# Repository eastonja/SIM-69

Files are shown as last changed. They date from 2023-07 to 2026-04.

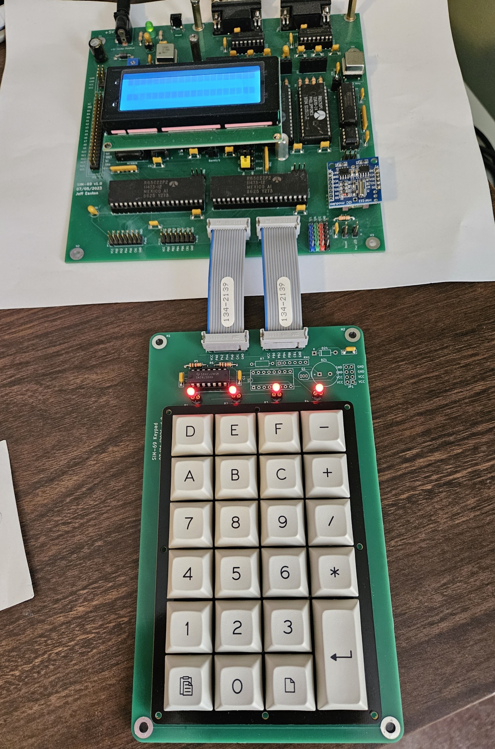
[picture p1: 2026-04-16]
SIM-69 Keypad v1.0/SIM-69-KeypadOperation.JPG

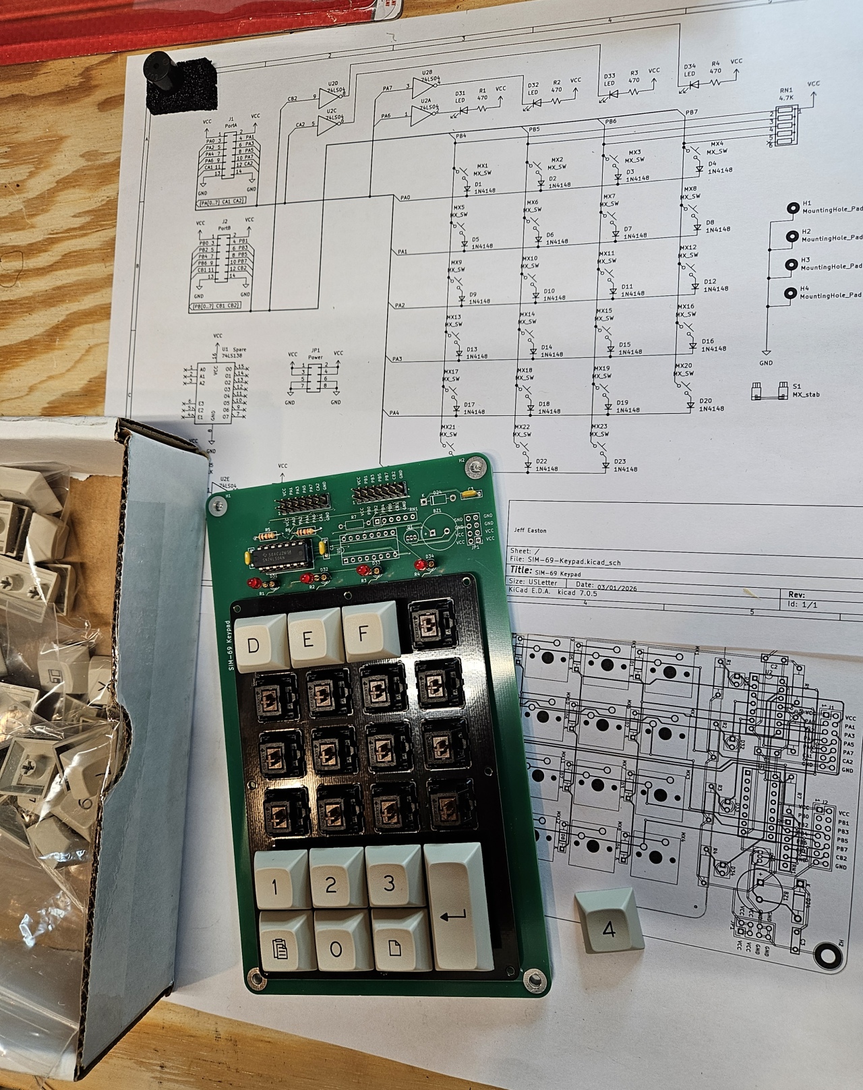
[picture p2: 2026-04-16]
SIM-69 Keypad v1.0/SIM-69-KeypadAssembly.JPG

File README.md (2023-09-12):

6809 based Retro Computing project.  Mini-ITX sized board with 6809 at 2Mhz, 32K/64K RAM, ROM, 8K-32K EEPROM,
20x4 LCD interface, 2 RS-232 Serial ports (6551), 4 8-bit parallel ports (6522), I2C interface(PCF 8584), 
RTC (via typical I2C module), 24LC256 serial EEPROM.
Can be used as a SBC for experimenting, or mounted in a mini-ITX case with Peter Hizalev's VT100 terminal
daughter board for a self contained computer.

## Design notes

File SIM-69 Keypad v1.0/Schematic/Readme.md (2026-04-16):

KiCad 7.x schematic and Bill of Materials for Keypad

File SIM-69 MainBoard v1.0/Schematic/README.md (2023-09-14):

KiCad 7.x schematic and Bill of Materials

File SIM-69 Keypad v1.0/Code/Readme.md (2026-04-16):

Demo Assembly code for scanning keypad and setting LEDs

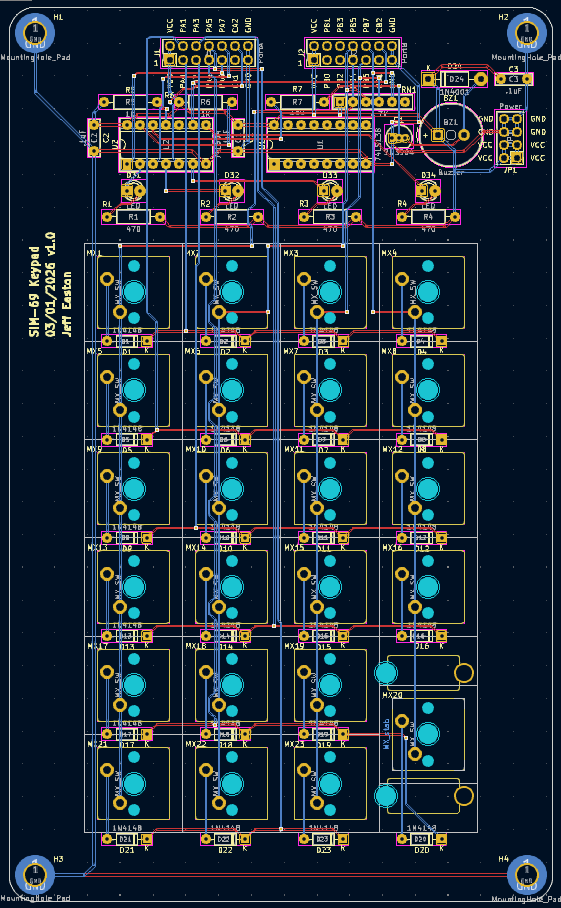
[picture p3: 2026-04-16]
SIM-69 Keypad v1.0/PCB/SIM-69-KeypadBRD.png

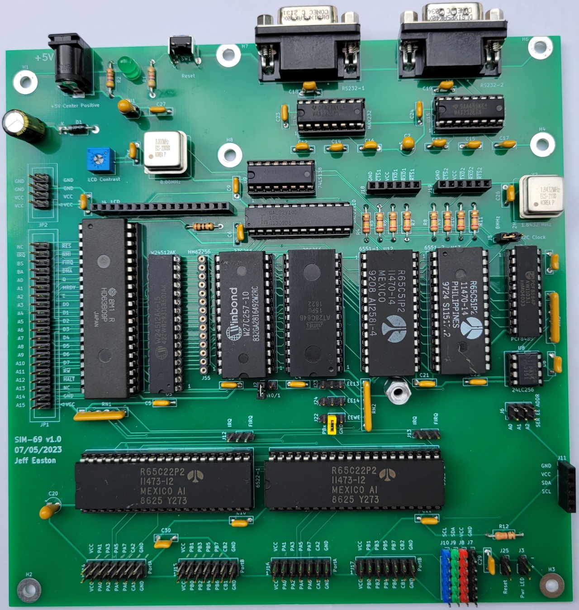
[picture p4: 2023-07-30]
SIM-69 MainBoard v1.0/SIM-69-PCB.jpg

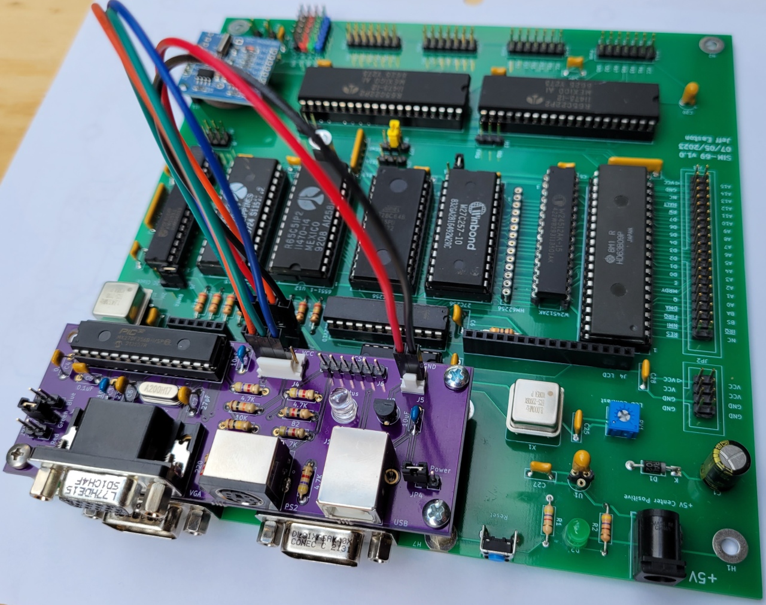
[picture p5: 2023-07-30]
SIM-69 MainBoard v1.0/SIM-69-TERM.jpg

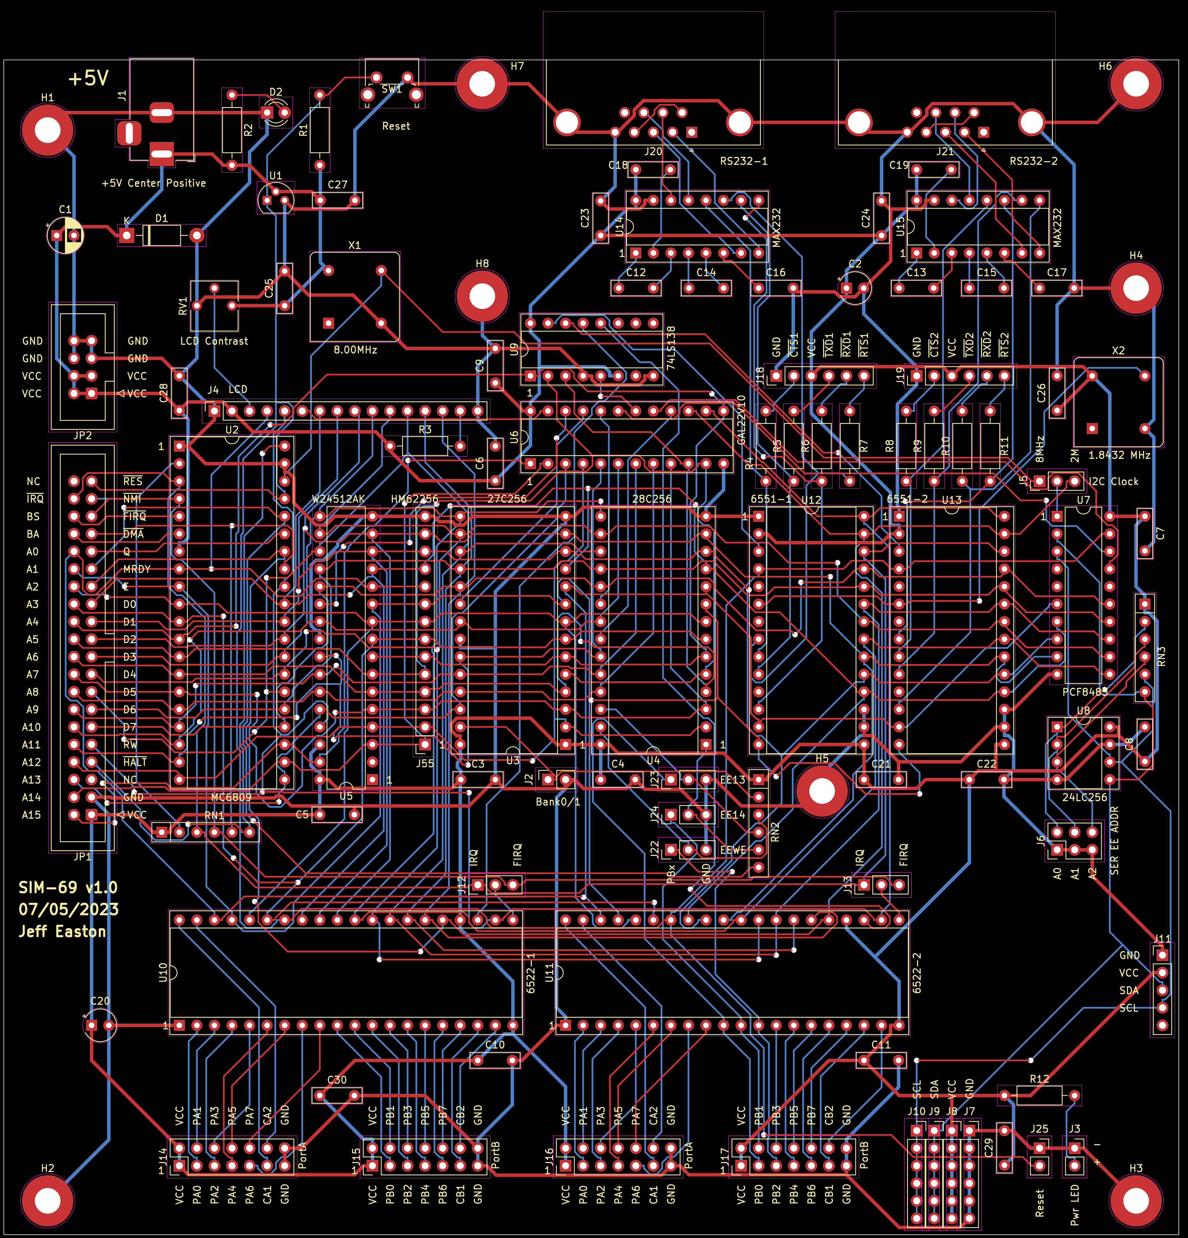
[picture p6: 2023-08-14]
SIM-69 MainBoard v1.0/PCB/SIM-69-brd.png

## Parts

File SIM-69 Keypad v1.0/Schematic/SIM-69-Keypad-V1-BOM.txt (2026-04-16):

				
Component Count:	74						
Ref	Qnty	Value	Cmp name	Footprint	Description	Vendor	DNP
BZ1	1	Buzzer	Buzzer	Buzzer_Beeper:Buzzer_TDK_PS1240P02BT_D12.2mm_H6.5mm	"Buzzer, polarized"		
"C1, C2, C3"	3	.1uF	C	Capacitor_THT:C_Rect_L7.0mm_W2.0mm_P5.00mm	Unpolarized capacitor		
D1 through D23	23	1N4148	D_Small	Diode_THT:D_DO-35_SOD27_P7.62mm_Horizontal	"Diode, small symbol"		
D24	1	1N4001	1N4002_1	Diode_THT:D_DO-41_SOD81_P10.16mm_Horizontal	"100V 1A General Purpose Rectifier Diode, DO-41"		
"D31, D32, D33, D34"	4	LED	LED	LED_THT:LED_D3.0mm	Light emitting diode		
"H1, H2, H3, H4"	4	MountingHole_Pad	MountingHole_Pad	MountingHole:MountingHole_3.7mm_Pad_TopBottom	Mounting Hole with connection		
J1	1	PortA	Conn_02x07_Odd_Even	Connector_PinHeader_2.54mm:PinHeader_2x07_P2.54mm_Vertical	"Generic connector, double row, 02x07, odd/even pin numbering scheme (row 1 odd numbers, row 2 even numbers)"		
J2	1	PortB	Conn_02x07_Odd_Even	Connector_PinHeader_2.54mm:PinHeader_2x07_P2.54mm_Vertical	"Generic connector, double row, 02x07, odd/even pin numbering scheme (row 1 odd numbers, row 2 even numbers)"		
JP1	1	Power	Conn_02x04_Odd_Even	Connector_PinHeader_2.54mm:PinHeader_2x04_P2.54mm_Vertical	"Generic connector, double row, 02x04, odd/even pin numbering scheme (row 1 odd numbers, row 2 even numbers)"		
MX1 through MX23	23	MX_SW	MX_SW_solder	PCM_marbastlib-mx:SW_MX_1u	"Push button switch, normally open, two pins, 45° tilted. Cherry MX Brown"		
Q1	1	2N3904	2N3904	Package_TO_SOT_THT:TO-92_Inline	"0.2A Ic, 40V Vce, Small Signal NPN Transistor, TO-92"		
"R1, R2, R3, R4"	4	470	R_Small_US	Resistor_THT:R_Axial_DIN0207_L6.3mm_D2.5mm_P10.16mm_Horizontal	"Resistor, small US symbol"		1/4W 5% carbon film
"R5, R6"	2	1K	R_Small_US	Resistor_THT:R_Axial_DIN0207_L6.3mm_D2.5mm_P10.16mm_Horizontal	"Resistor, small US symbol"		1/4W 5% carbon film
R7	1	180	R_Small_US	Resistor_THT:R_Axial_DIN0207_L6.3mm_D2.5mm_P10.16mm_Horizontal	"Resistor, small US symbol"		1/4W 5% carbon film
RN1	1	4.7K	R_Network05	"Resistor_THT:R_Array_SIP6 (Optional, depending on 6522 VIA mfr)"	"5 resistor network, star topology, bussed resistors, small symbol"		
S1	1	MX_stab	MX_stab	"PCM_marbastlib-mx:STAB_MX_P_2u, DUROCK Stabilizer V3 PCB Mount"	Cherry MX-style stabilizer	Amazon	
U1	1	74LS138	74LS138	Package_DIP:DIP-16_W7.62mm_Socket (Optional/ Spare)	Decoder 3 to 8 active low outputs		
U2	1	74LS04	74LS04	Package_DIP:DIP-14_W7.62mm_Socket	Hex Inverter		
							
			PCB	Sim-69 Keypad base PCB		JLCPCB	https://jlcpcb.com/
			Plate	"Nyquist Plate, Black FR4 (optional)"		Keebio	https://keeb.io/products/nyquist-case-plates
			2x7 ribbon cable/conn	"2x7 IDC dual row female connectors, 14 con. Ribbon cable"		Jameco/Amazon	
			KeyCaps	"DSA Flex Keycaps, Hexidecimal set and Numpad Modifier set in Biege"		Signature Plastics	https://spkeyboards.com/products/dsa-flex-sublimated-keycaps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

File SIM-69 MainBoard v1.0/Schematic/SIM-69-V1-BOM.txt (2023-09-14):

Reference	Value	Footprint	Datasheet	Sim.Device	Sim.Pins	Qty														
C1	470uF	Capacitor_THT:CP_Radial_D5.0mm_P2.50mm	~			1		EEU-FM1A471B Panasonic Electronic Components | Capacitors | DigiKey												
"C2, C20"	10uF	Capacitor_THT:CP_Radial_Tantal_D4.5mm_P2.50mm	~			2		TAP106K016SRW KYOCERA AVX | Capacitors | DigiKey												
"C3-C9, C11, C21-C27, C29, C30"	.1uF	Capacitor_THT:C_Rect_L7.0mm_W2.0mm_P5.00mm	~			17		SR211C104KARTR1 KYOCERA AVX | Capacitors | DigiKey												
"C10, C28"	.1uF	Capacitor_THT:C_Rect_L7.0mm_W2.0mm_P5.00mm	~			2		SR211C104KARTR1 KYOCERA AVX | Capacitors | DigiKey												
C12-C19	1uF	Capacitor_THT:C_Rect_L7.0mm_W2.0mm_P5.00mm	~			8		SR211C105KAR KYOCERA AVX | Capacitors | DigiKey												
D1	1N4002	Diode_THT:D_DO-41_SOD81_P10.16mm_Horizontal	http://www.vishay.com/docs/88503/1n4001.pdf	D	1=K 2=A	1		1N4002 Diode | Jameco Electronics												
D2	LED	LED_THT:LED_D3.0mm	~			1		SSL-LX5093GD-12V Lumex Opto/Components Inc. | Optoelectronics | DigiKey												
H1-H8	MountingHole_Pad	MountingHole:MountingHole_3.7mm_Pad_TopBottom	~			8														
J1	+5V Center Positive	Connector_BarrelJack:BarrelJack_Horizontal	~			1		"PJ-202AH CUI Devices | Connectors, Interconnects | DigiKey"												
J2	Bank0/1	Connector_PinSocket_2.54mm:PinSocket_1x02_P2.54mm_Vertical	~		1x2 pin header strip	1		"68000-220HLF Amphenol ICC (FCI) | Connectors, Interconnects | DigiKey"												
J3	Front Panel Power LED	Connector_PinSocket_2.54mm:PinSocket_1x02_P2.54mm_Vertical	~		1x2 pin header strip	1		"68000-220HLF Amphenol ICC (FCI) | Connectors, Interconnects | DigiKey"												
J4	LCD Interface	Connector_PinSocket_2.54mm:PinSocket_1x16_P2.54mm_Vertical	~		1x16 socket header strip	1		Vertical Header Receptacle TDH16SG-VP-R | Jameco Valuepro												
J5	I2C CLK	Connector_PinHeader_2.54mm:PinHeader_1x03_P2.54mm_Vertical	~		1x3 pin header strip	1		"68000-220HLF Amphenol ICC (FCI) | Connectors, Interconnects | DigiKey"												
J6	Ser ADDR	Connector_PinHeader_2.54mm:PinHeader_2x03_P2.54mm_Vertical	~		2x3 pin header strip	1		"67997-240HLF Amphenol ICC (FCI) | Connectors, Interconnects | DigiKey"												
J7	I2C GND	Connector_PinSocket_2.54mm:PinSocket_1x06_P2.54mm_Vertical	~		1x6 pin header strip	1		"colored .100"" pin strip Amazon"												
J8	I2C Vcc	Connector_PinSocket_2.54mm:PinSocket_1x06_P2.54mm_Vertical	~		1x6 pin header strip	1		"colored .100"" pin strip Amazon"												
J9	I2C SDA	Connector_PinSocket_2.54mm:PinSocket_1x06_P2.54mm_Vertical	~		1x6 pin header strip	1		"colored .100"" pin strip Amazon"												
J10	I2C SCL	Connector_PinSocket_2.54mm:PinSocket_1x06_P2.54mm_Vertical	~		1x6 pin header strip	1		"colored .100"" pin strip Amazon"												
J11	RTC Conn	Connector_PinHeader_2.54mm:PinHeader_1x05_P2.54mm_Vertical	~		1x5 socket header strip	1		"RS1-05-G Adam Tech | Connectors, Interconnects | DigiKey"												
"J12, J13"	6522 IRQ	Connector_PinHeader_2.54mm:PinHeader_1x03_P2.54mm_Vertical	~		1x3 pin header strip	2		"68000-220HLF Amphenol ICC (FCI) | Connectors, Interconnects | DigiKey"												
"J14, J16"	PortA	Connector_PinHeader_2.54mm:PinHeader_2x07_P2.54mm_Vertical	~		2x7 pin header strip	2		"67997-240HLF Amphenol ICC (FCI) | Connectors, Interconnects | DigiKey"												
"J15, J17"	PortB	Connector_PinHeader_2.54mm:PinHeader_2x07_P2.54mm_Vertical	~		2x7 pin header strip	2		"67997-240HLF Amphenol ICC (FCI) | Connectors, Interconnects | DigiKey"												
J18	Conn_Ser1	Connector_PinHeader_2.54mm:PinHeader_1x06_P2.54mm_Vertical	~		1x6 socket header strip	1		"RS1-06-G Adam Tech | Connectors, Interconnects | DigiKey"												
J19	Conn_Ser2	Connector_PinHeader_2.54mm:PinHeader_1x06_P2.54mm_Vertical	~		1x6 socket header strip	1		"RS1-06-G Adam Tech | Connectors, Interconnects | DigiKey"												
"J20, J21"	DE9_P	Connector_Dsub:DSUB-9_Male_Horizontal_P2.77x2.84mm_EdgePinOffset7.70mm_Housed_MountingHolesOffset9.12mm	 ~		DB9 Male rt angle	2		"DLS1XP5AK40X Conec | Connectors, Interconnects | DigiKey"												
J22	~{EEWE}	Connector_PinHeader_2.54mm:PinHeader_1x03_P2.54mm_Vertical	~		1x3 pin header strip	1		"68000-220HLF Amphenol ICC (FCI) | Connectors, Interconnects | DigiKey"												
J23	EE13	Connector_PinHeader_2.54mm:PinHeader_1x03_P2.54mm_Vertical	~		1x3 pin header strip	1		"68000-220HLF Amphenol ICC (FCI) | Connectors, Interconnects | DigiKey"												
J24	EE14	Connector_PinHeader_2.54mm:PinHeader_1x03_P2.54mm_Vertical	~		1x3 pin header strip	1		"68000-220HLF Amphenol ICC (FCI) | Connectors, Interconnects | DigiKey"												
J25	Front Panel Reset	Connector_PinSocket_2.54mm:PinSocket_1x02_P2.54mm_Vertical	~		1x2 pin header strip	1		"68000-220HLF Amphenol ICC (FCI) | Connectors, Interconnects | DigiKey"												
J55	HM62256	Connector_PinSocket_2.54mm:PinSocket_1x14_P2.54mm_Vertical	~		machined strip	1		SMC-1-30-1-GT Adam Technologies | Jameco												
JP1	EXP BUS	Connector_IDC:IDC-Header_2x20_P2.54mm_Vertical	~		2x20 pin header strip	1		"67997-240HLF Amphenol ICC (FCI) | Connectors, Interconnects | DigiKey"												
JP2	Power	Connector_IDC:IDC-Header_2x04_P2.54mm_Vertical	~		2x4 pin header strip	1		"67997-240HLF Amphenol ICC (FCI) | Connectors, Interconnects | DigiKey"												
R1	2.7K	Resistor_THT:R_Axial_DIN0207_L6.3mm_D2.5mm_P10.16mm_Horizontal	~			1		Carbon Film Resistor 1/4 Watt 2.7k Ohm | Jameco Valuepro												
"R2, R12"	470	Resistor_THT:R_Axial_DIN0207_L6.3mm_D2.5mm_P10.16mm_Horizontal	~			2		Carbon Film Resistor 1/4 Watt 470 Ohm | Jameco Valuepro												
R3	10	Resistor_THT:R_Axial_DIN0207_L6.3mm_D2.5mm_P10.16mm_Horizontal	~			1		Carbon Film Resistor 1/4 Watt 10 Ohm | Jameco Valuepro												
R4-R11	240	Resistor_THT:R_Axial_DIN0207_L6.3mm_D2.5mm_P10.16mm_Horizontal	~			8		Carbon Film Resistor 1/4 Watt 240 Ohm | Jameco Valuepro												
RN1-RN3	4.7K	Resistor_THT:R_Array_SIP6	http://www.vishay.com/docs/31509/csc.pdf			3		4606X-101-472LF Bourns Inc. | Resistors | DigiKey												
RV1	10K_Potentiometer	Potentiometer_THT:Potentiometer_Vishay_T73YP_Vertical	~			1		"T73YP103KT20 Vishay Sfernice | Potentiometers, Variable Resistors | DigiKey"												
SW1	SW_Push	Button_Switch_THT:SW_Tactile_SPST_Angled_PTS645Vx58-2LFS	~			1		PTS645VK58-2 LFS C&K | Switches | DigiKey							alternate: PTS645VM31-2 LFS C&K | Switches | DigiKey					alternate: PTS645VK312LFS C&K | Switches | DigiKey
U1	DS1813-5	Package_TO_SOT_THT:TO-92				1		DS1813-5+ Analog Devices Inc./Maxim Integrated | Integrated Circuits (ICs) | DigiKey								alternate: Microschip MCP130			alternate:10uf Tantlum cap	
U2	MC6809	Package_DIP:DIP-40_W15.24mm_Socket	http://pdf.datasheetcatalog.com/datasheet/motorola/MC68B09S.pdf			1		MC6809B or HD63B09P | Ebay												
U2		40Pin DIP socket						"DILB40P-223TLF Amphenol ICC (FCI) | Connectors, Interconnects | DigiKey"												
U3	27C256	Package_DIP:DIP-28_W15.24mm_Socket	http://ww1.microchip.com/downloads/en/DeviceDoc/doc0014.pdf			1		WinBond W27C257-10 | Ebay												
U3		28Pin DIP Socket						"DILB28P-223TLF Amphenol ICC (FCI) | Connectors, Interconnects | DigiKey"												
U4	28C256	Package_DIP:DIP-28_W15.24mm_Socket	http://ww1.microchip.com/downloads/en/DeviceDoc/doc0006.pdf			1		Atmel AT28C64B-15 (8Kx8) or AT28C256 (32Kx8) | Ebay												
U4		28Pin DIP Socket						"DILB28P-223TLF Amphenol ICC (FCI) | Connectors, Interconnects | DigiKey"												
U5	W24512AK	Package_DIP:DIP-32_W7.62mm	https://pdf1.alldatasheet.com/datasheet-pdf/view/47639/WINBOND/W24512AK-15.html			1		W24512AK-15 (64Kx8) or UM61512AK-15 (64Kx8) or HM62256 (32Kx8) | Ebay												
U5		32Pin DIP socket narrow 						two 16pin sockets stacked end to end.	IC Socket 16MTLP | Jameco Valuepro or use machined strip header sockets											
U6	GAL22V10	Package_DIP:DIP-24_W7.62mm_Socket	~			1		GAL22V10D-10LP | Ebay												
U6		24Pin DIP socket narrow						16pin and 8 pin narrow socket stacked end to end												
U7	PCF8584	Package_DIP:DIP-20_W7.62mm	http://www.nxp.com/documents/data_sheet/PCF8584.pdf			1		PCF8584P | Ebay												
U7		20Pin dip socket narrow						"DILB20P-223TLF Amphenol ICC (FCI) | Connectors, Interconnects | DigiKey"												
U8	24LC256	Package_DIP:DIP-8_W7.62mm_Socket	http://ww1.microchip.com/downloads/en/devicedoc/21203m.pdf			1		24LC256-I-P EEPROM Memory Microchip Technology | Jameco												
U8		8 pin DIP socket						IC Socket 24LPD.3 | Jameco Electronics												
U9	74LS138	Package_DIP:DIP-16_W7.62mm_Socket	http://www.ti.com/lit/gpn/sn74LS138			1		CD74HCT138E Texas Instruments | Integrated Circuits (ICs) | DigiKey Marketplace												
U9		16{in DIP socket						"DILB16P-223TLF Amphenol ICC (FCI) | Connectors, Interconnects | DigiKey"												
"U10, U11"	65C22	Package_DIP:DIP-40_W15.24mm_Socket	http://www.6502.org/documents/datasheets/mos/mos_6522_preliminary_nov_1977.pdf			2		R65C22P2 | Ebay												
"U10, U11"		40Pin DIP socket						"DILB40P-223TLF Amphenol ICC (FCI) | Connectors, Interconnects | DigiKey"												
"U12, U13"	65C51	Package_DIP:DIP-28_W15.24mm_Socket	http://www.6502.org/documents/datasheets/mos/mos_6551_acia.pdf			2		R65C51P2 | Ebay												
"U12, U13"		28Pin DIP socket						"DILB28P-223TLF Amphenol ICC (FCI) | Connectors, Interconnects | DigiKey"												
"U14, U15"	MAX232	Package_DIP:DIP-16_W7.62mm_Socket	http://www.ti.com/lit/ds/symlink/max232.pdf			2		MAX232EIN Texas Instruments | Integrated Circuits (ICs) | DigiKey Marketplace												
"U14, U15"		16Pin DIP Socket						"DILB16P-223TLF Amphenol ICC (FCI) | Connectors, Interconnects | DigiKey"												
X1	8.00MHz	Oscillator:Oscillator_DIP-8	http://cdn-reichelt.de/documents/datenblatt/B400/OSZI.pdf			1		"ECS-2200BX-080 ECS Inc. | Crystals, Oscillators, Resonators | DigiKey"												
X2	1.8432 Mhz	Oscillator:Oscillator_DIP-8	http://cdn-reichelt.de/documents/datenblatt/B400/OSZI.pdf			1		"ECS-2100A-018 ECS Inc. | Crystals, Oscillators, Resonators | DigiKey"												
		4/8Pin DIP socket machined				2		1108800 Aries Electronics IC Socket | Jameco Electronics												
																				
	330	1/4 watt resistor (alternate for front panel power led) R12						alternate for front panel power led resistor R12 (depending on current draw of case power LED												
																				
		"vt100 brd  cable Molex 2695 terminal 2759, 6459, 41572"						"0008650804 Molex | Connectors, Interconnects | DigiKey"						for TTL serial cables						
		vt100 data cable Molex 2695 4 pos housing						"0022013047 Molex | Connectors, Interconnects | DigiKey"						for serial TTL cables						
		vt100 pwr cable Molex 2695 2 pos housing																		
																				
		Wall wart power supply						Jameco 252720  AC to DC Power Supply Wall Adapter Single Output 5 Volt 1 Amp 5 Watt36

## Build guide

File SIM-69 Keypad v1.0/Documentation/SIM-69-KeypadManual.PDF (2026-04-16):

Jeff Easton
V1.0 04/16/2026

SIM-69-Keypad

DESCRIPTION
SIM-69-Keypad is an add on board to aach to the SIM-69 Motherboard that provides for a 6 row by 4 column keypad and four controllable LEDs. The keypad board aaches to either of the VIA PortA and PortB connectors on the motherboard.

HARDWARE
The keypad uses many of the PortA and PortB lines from one of the VIAs on the motherboard. It has been designed to work around the exisng port pins that are used from VIA 6522-2 PortB that can be used for bank switching the EEPROM on the motherboard. Thus the only logic on the keypad PCB is a single 74LS04, primarily used to drive the LEDs since the VIA output pins alone do not provide adequate current by themselves.

If the motherboard is using CMOS 6522 VIAs from Western Design Center, an oponal resistor pack can be installed at RN1 to provide the keypad matrix columns pull up resistors. Older NMOS and CMOS 6522s contain an internal pullup that the WDC part lacks, so those parts will not require the resistor pack.

A spare 16 pin DIP package and a buzzer circuit are on the PCB but not used.

OPERATION
PortA pins PA0 through PA5 are configured as outputs, and all set hi. PortB pins PB4 through PB7 are configured as inputs. This forms the 6x4 matrix of keys. PortA pins can be individually set low and the PortB pins read. If a low is seen on a PortB pin, a key in the matrix has been pressed. 1N4148 signal diodes are used to eliminate ghosng.

The LEDs can be controlled individually by the remaining unused port pins on the VIA; PA6, PA7, CA2 and CB2. These would be configured as outputs and set hi to light an LED..

PARTS
The keypad PCB was designed with the Keebio Nyquist key plate in mind, to keep the cherry MX switches aligned properly. This plate is oponal but if not using a plate, you may noce your keycaps are not uniformly spaced between rows and columns, as each switch may be rotated slightly when soldered to the PCB. The lower right key is a 2U keycap for an enter key, and it required a 2U stabilizer for smooth operaon. A PCB or “screw in” stabilizer is used.

Since the Keebio Nyquist plate is really designed for a landscape layout, and we are using it in a portrait layout, the cherry MX switches are laid out 90 degrees rotated from what would be considered “normal” on the PCB. This allows the switches to snap into the plate snugly. There is no operaonal or physical difference due to the rotaon as the keys switches are square, and the stems are centered in either orientaon.

Signature Plascs sells several keycap sets, including a set that contains the full Hexadecimal keys, 0-9 and A-F. Check the Bill Of Materials list for suggesons on where to get the “specialty” parts.

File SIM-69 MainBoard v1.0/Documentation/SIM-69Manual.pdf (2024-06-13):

Jeff Easton
V1.1 06/06/2024

SIM-69

DESCRIPTION
SIM-69 is a Motorola MC6809 based single board computer running at 2Mhz and comes with a full complement of I/O for interfacing, including an I2C bus. The board can be mounted in a Mini-ITX case if desired.

HARDWARE
SIM-69 is based on the Motorola MC68B09, or Hitachi CMOS version, the HD63B09 and is located at U2. This design uses the internal clock version, not the “E” version of the 6809 CPU that requires an external quadrature clock generator. This simplifies the design somewhat and only requires a single 8.00Mhz crystal oscillator at X1 to run the system with a bus frequency of 2.00Mhz. A Power Design chip is provided at U1 to generate a clean power up reset signal for the CPU, along with a reset button at SW1 and a connector for a case Reset button at J25 if desired. Full CPU bus signals are provided on 40 pin connector JP1 for use in expanding the system if desired. Additional +5v and Ground pins are provided on connector JP2.

Address decoding is done by a pair of IC’s, a GAL22V10 and a 74LS138 (or 74HCT138). Two versions of the GAL code are provided, depending on the type and size of RAM chip used for system RAM. A 32K GAL is used if a HM62256 RAM chip is installed. A 64K GAL is used if a W24512AK RAM chip is installed. Note that only a total of 42KB of the 64KB ram chip is usable as ROM and I/O take up the remaining space in the 64KB address map.

System RAM is either a “skinny”DIP 64KB ram chip at U5 or a 32KB “wide” DIP chip inserted across the U5 and J55 connector.

System ROM is a 27C256 style chip used at U3. Only 12KB of ROM space is decoded at the upper end of the memory map. Address line A14 of U3 is brought out to a Jumper at J2 to allow bank switching the ROM. For example, a monitor ROM can be burned into one half of the chip and Extended Basic can be burned into the other half, then the system can boot into either code at power up depending on the jumper at J2.

J2 ROM bank switch
J2 | 1-2 | jumper removed | Access upper half of ROM
| 1-2 | jumper installed | Access lower half of ROM

Non-volatile storage is accomplished with an EEPROM at U4. Either a AT28C64 or AT28C256 can be used. The EEPROM is mapped into 8KB of space in the memory map. If a AT28C256 is used, the total 32KB of EEPROM in the chip is bank switched into that 8KB space, either manually or programmatically using VIA2 Port B pins. This is selected by J23 and J24. Also, the Write Enable on the EEPROM is controlled either manually or programmatically with a VIA2 port B pin using J22. Code is provided in the SmartBug monitor to automatically select pages (or Banks) to read and write from the EEPROM if J22, J23, J24 are all set to pins 1-2.

J22, J23, J24 EEPROM Bank Addressing and Write Enable
J22 | 1-2 | jumper installed | /WE software controlled by VIA2 PB2
| 2-3 | jumper installed | EEPROM in Write Enabled state
| | no jumper | EEPROM is Read Only
Bank J23 | J24
1-2 | 1-2 | Bank Switching software controlled by VIA2 PB0 and PB1
2-3 | 2-3 | Manual Bank 0
2-3 | NC | Manual Bank 1
NC | 2-3 | Manual Bank 2
NC | NC | Manual Bank 3

A LCD2004a style 20x4 LCD panel can be mounted on the motherboard at J4. This LCD is directly on the CPU bus and is address decoded by the GAL. LCD contrast can be adjusted by RV1 potentiometer. Backlight power is provided by R3. Subroutines are provided in the SmartBug monitor for initializing and displaying text on the LCD panel.

Two serial ports are provided by U12 and U13 with type 65B51 ACIA’s. SmartBug only uses Serial Port 1, leaving the second serial port free for other uses. Both serial ports use crystal oscillator X2 for baud rate generation. Baud rates are available up to 38.4Kbaud, in the case of serial port1 this is selectable by a command in SmartBug and defaults to 19.2K. Both serial ports are available on DB9 connectors. If it is desired to use a FTDI style USB to Serial converter, connectors J18 and J19 are available for use, after the corresponding MAX232 level shifter chip is removed from its socket at U14 or U15. Note that some USB to Serial converters supply +5V power from the USB port. To prevent back feeding the SIM-69 board from USB, bend out or cut off the Vcc pin on the converter board. Mounting holes are provided for use with standoffs to allow Peter Hizalev's VT100 terminal daughter board to be mounted on the SIM-69 board and then a PS/2 style keyboard and VGA monitor can be used. See Peter’s Tindie page for purchasing his VT100 board.

Two 65B22 VIA’s are located at U10 and U11 to provide parallel IO ports and timers. Each VIA can have its Interrupt pin mapped to either the IRQ or FIRQ of the CPU via Jumpers J12 and J13. All parallel IO pins are available at Connectors J14 through J17. Note that VIA2 PortB pins PB0 – PB2 are also used to control the bank switching of the EEPROM, if used and configured with jumpers J22 – J24.

J12 | VIA-1 Interrupt
1-2 | VIA-1 sends interrupt to CPU /IRQ
2-3 | VIA-1 sends interrupt to CPU /FIRQ
J13 | VIA-2 Interrupt
1-2 | VIA-2 sends interrupt to CPU /IRQ
2-3 | VIA-2 sends interrupt to CPU /FIRQ

An I2C bus is provided by the PCF8584 chip at U7. Clocking for the I2C bus is derived from the 8Mhz clock provided by X1. If the CPU bus speed is increased above 2Mhz by using a faster crystal oscillator, the I2C bus timing can be out of specification. Jumper J5 is used to select a slower clock to bring the I2C bus back under spec in these cases. Two I2C devices are provided for on the motherboard and connectors J7 – J10 are provided to connect up to 6 additional external I2C peripherals. Note that Smartbugs initialization routines attempts to initialize and configure the PCF8584 at power up and may hang if the chip is not present.

J5 | I2C Clock Source
1-2 | 8Mhz clock (main clock for CPU)
2-3 | 2Mhz clock (E clock from CPU)

A 24LC256 32K serial EEPROM is provided at U8. Its I2C address is selectable using jumpers at J6, if another I2C device conflicts with the default address. Sample subroutines are provided in SmartBug to read and write the serial EEPROM at the default address.

J6 Serial EEPROM I2C slave address
Address
out | out | out | 1010111 | (default)
5-6 | 3-4 | 1-2 | 1010000
5-6 | 3-4 | out | 1010001
5-6 | out | 1-2 | 1010010
5-6 | out | out | 1010011
out | 3-4 | 1-2 | 1010100 | etc.

A HW-111 style I2C Real Time Clock module can be installed on connector J11. Commands are provided in SmartBug to read and write the clock chip for time and date.

Connectors J3 and J25 are provided for connection to a Power LED and Reset button on a Mini-ITX case front panel if desired.

Power for the SIM-69 system is provided by an external “wall wart” style +5V DC power adaptor. Note there is no power regulation done on the SIM-69 board. Be very careful to use only a +5VDC adaptor and note the polarity voltage at Jack J1. The center pin is positive. A 2 Amp adapter is specified in the Bill of Materials. If all CMOS components are used on the motherboard, a 1 Amp adapter may be substituted.

Mounting Holes H1, H2, H3, and H4 are provided for installing the board into a mini-ITX case. Mounting hole H5 is used with a standoff to support the end of a LCD2004a module if installed. Mounting holes H4, H6, H7 and H8 are used with standoffs to support the optional VT100 board.

SOFTWARE

SmartBug is a ROM monitor written in the style of MikBug to allow entering and executing code on the SIM-69. It is contained in the ROM chip at the top 12KB of the memory map $D000 - $FFFF. At powerup or reset, SmartBug initialized the ACIA-1 and the I2C chip, sets up the Direct Page, Stack and User Stack areas, and initializes some space in RAM for variable storage. It also checks for the presence of auto starting code in the EEPROM by checking for a AUXROM flag and if found, passes control to the AUXROM cold start vector instead of dropping into the SmartBug prompt.

SmartBug Commands are upper case two letter commands used to enter, edit and execute code.

AI | ASCII INPUT
AO | ASCII OUTPUT
AU | AUTO MEMORY INPUT
BR | BAUD RATE
CL | DISPLAY/SET CLOCK
CP | COMPARE MEMORY BLOCKS
DS | DOWNLOAD S1 S9 FILES
DI | DOWNLOAD INTEL HEX FILES
ER | READ FROM EEPROM
EW | WRITE TO EEPROM
EX | EXAMINE MEMORY
FI | FIND BYTES
FL | FILL MEMORY
GO | GOTO PROGRAM
HE | HEX DUMP OF MEMORY
MO | MOVE A BLOCK OF MEMORY
PR | PRINTER ENABLE/DISABLE
UR | USER COMMAND
VR | ROM VERSION NUMBERS
XX | EXIT BACK TO PRIMARY TASK
?? | HELP SCREEN

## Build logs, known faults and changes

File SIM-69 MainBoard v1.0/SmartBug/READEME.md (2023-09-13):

SmartBug Monitor Program for SIM-69.  Burn in rom at $E000 to $FFFF  
At reset, at the '->' prompt, type '??' for a help menu of commands.  

        SMARTBUG /09 v1.27a-S69  
          WRITTEN 09/12/23  
           BY JEFF EASTON  
  
->??  
  
 CURRENT COMMANDS:  
   
AI  ASCII INPUT  
AO  ASCII OUTPUT  
AU  AUTO MEMORY INPUT  
BR  BAUD RATE  
CL  DISPLAY/SET CLOCK  
CP  COMPARE MEMORY BLOCKS  
DS  DOWNLOAD S1 S9 FILES  
DI  DOWNLOAD INTEL HEX FILES  
ER  READ FROM EEPROM  
EW  WRITE TO EEPROM  
EX  EXAMINE MEMORY  
FI  FIND BYTES  
FL  FILL MEMORY  
GO  GOTO PROGRAM  
HE  HEX DUMP OF MEMORY  
MO  MOVE A BLOCK OF MEMORY  
PR  PRINTER ENABLE/DISABLE  
UR  USER COMMAND  
VR  ROM VERSION NUMBERS  
XX  EXIT BACK TO PRIMARY TASK  
??  HELP SCREEN  
  
->

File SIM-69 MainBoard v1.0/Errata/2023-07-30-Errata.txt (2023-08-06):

Bugs in SIM-69 v1.0

[Documentation]  Schematic U6 Pin 23 is marked as /LCD.  This is not active Low but active Hi for the LCD enable.
[Mechanical]  	 Mounting Hole H5 which supports one end of the LCD2004a module via a standoff, is incorrectly shifted .100" to 
			the right.  Needs to be moved .100" to the left to properly line up with (most) LCD2004a modules mounting hole.

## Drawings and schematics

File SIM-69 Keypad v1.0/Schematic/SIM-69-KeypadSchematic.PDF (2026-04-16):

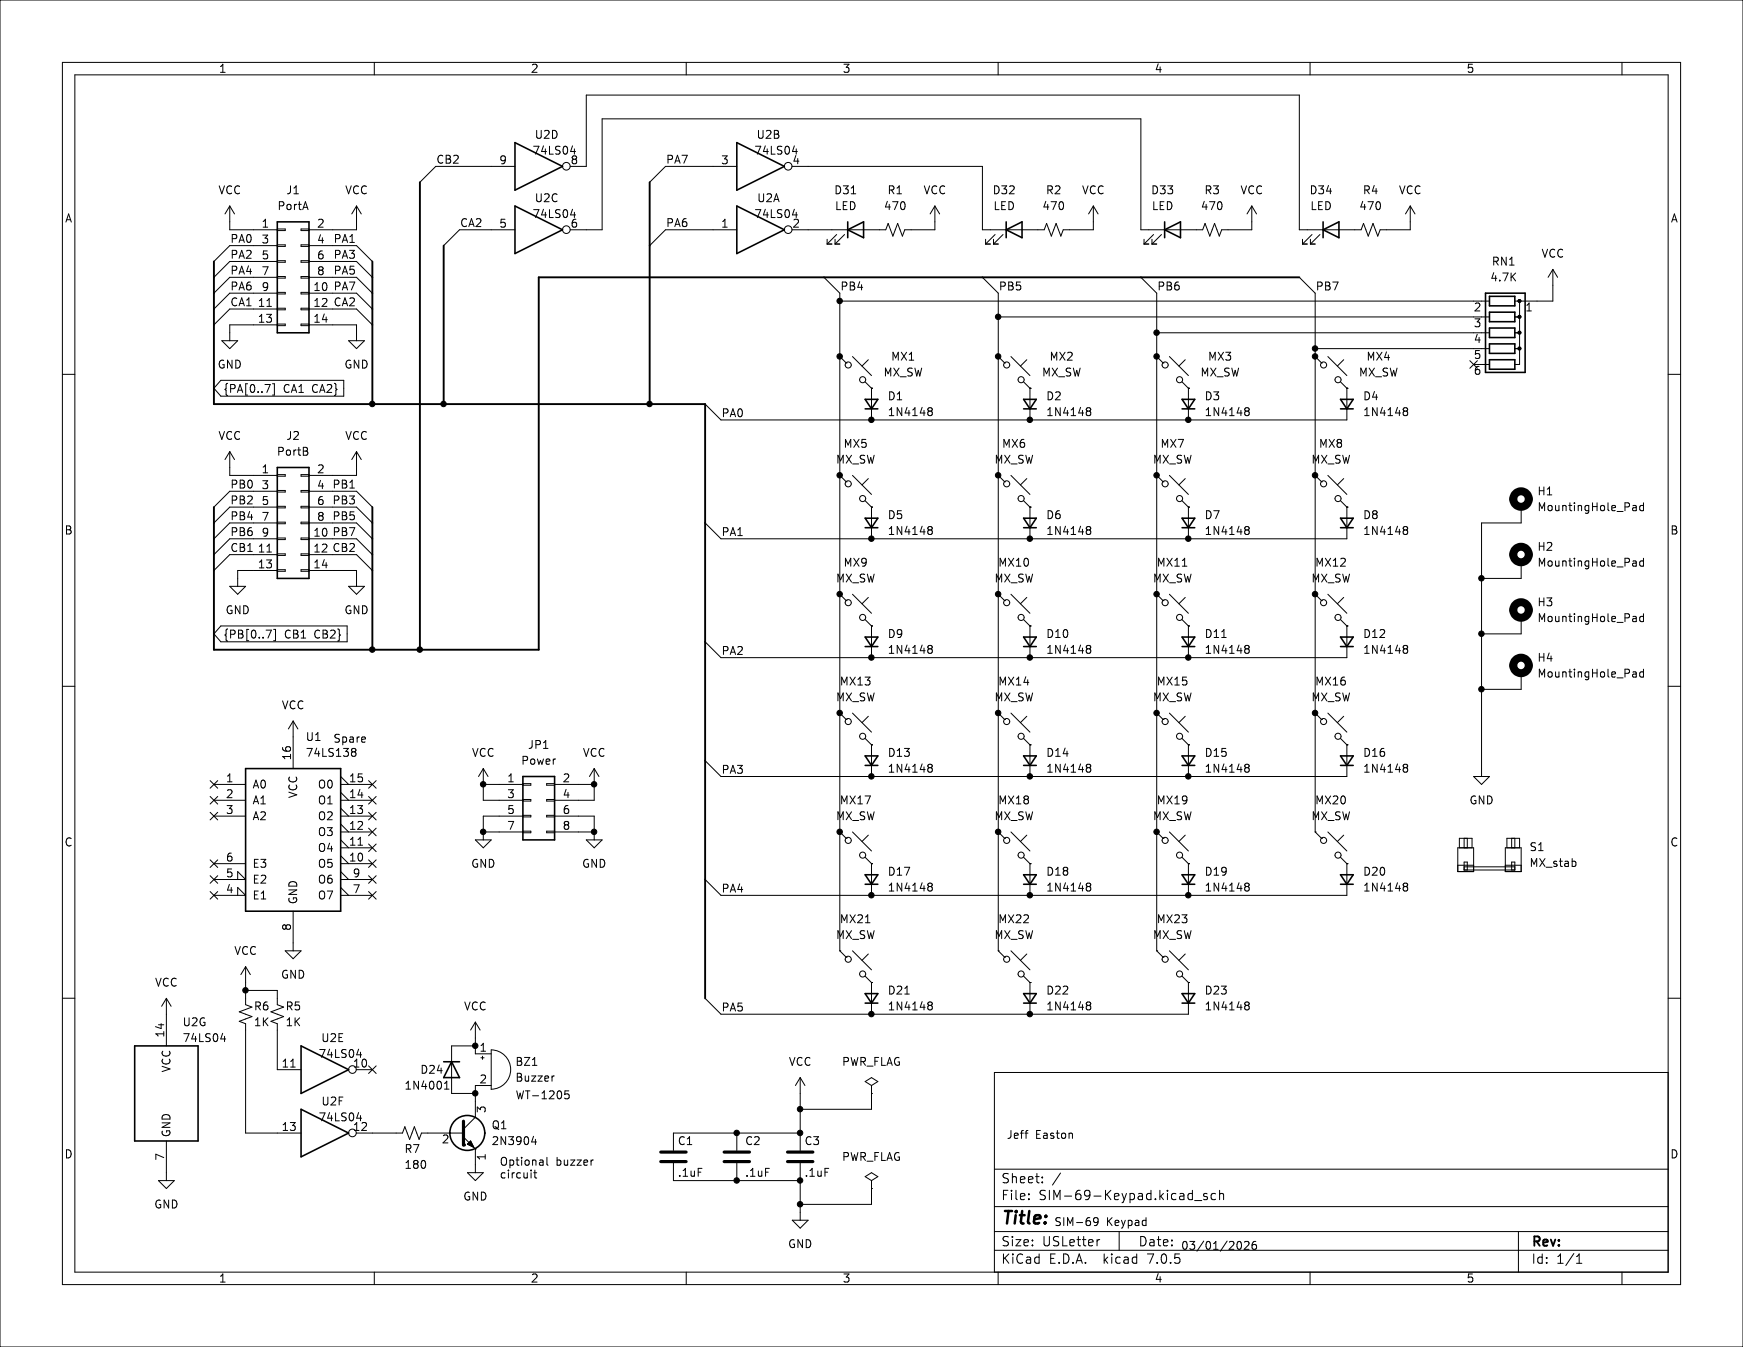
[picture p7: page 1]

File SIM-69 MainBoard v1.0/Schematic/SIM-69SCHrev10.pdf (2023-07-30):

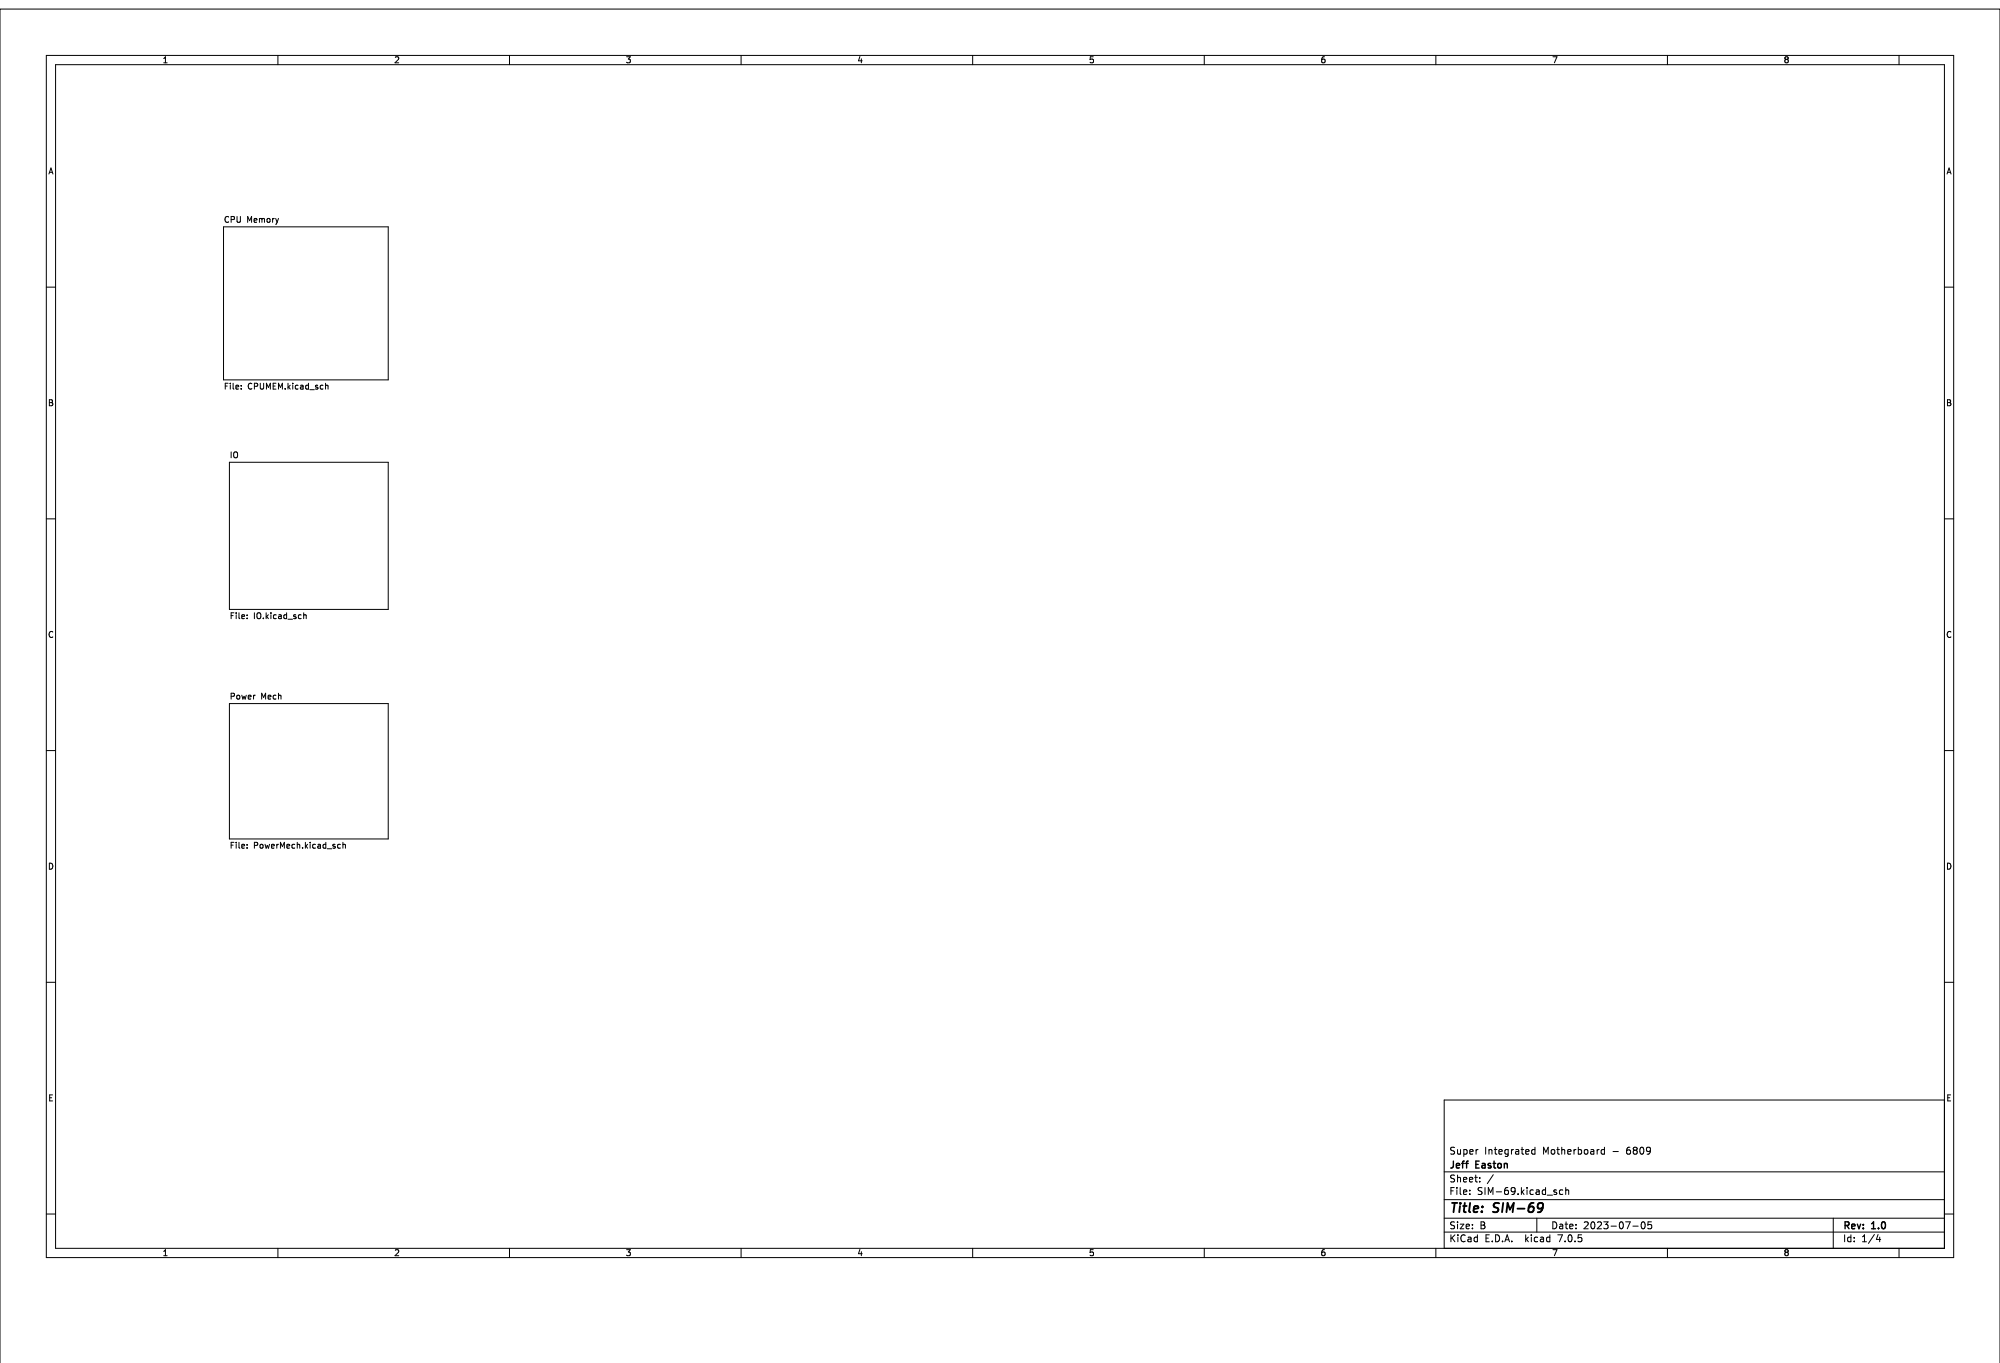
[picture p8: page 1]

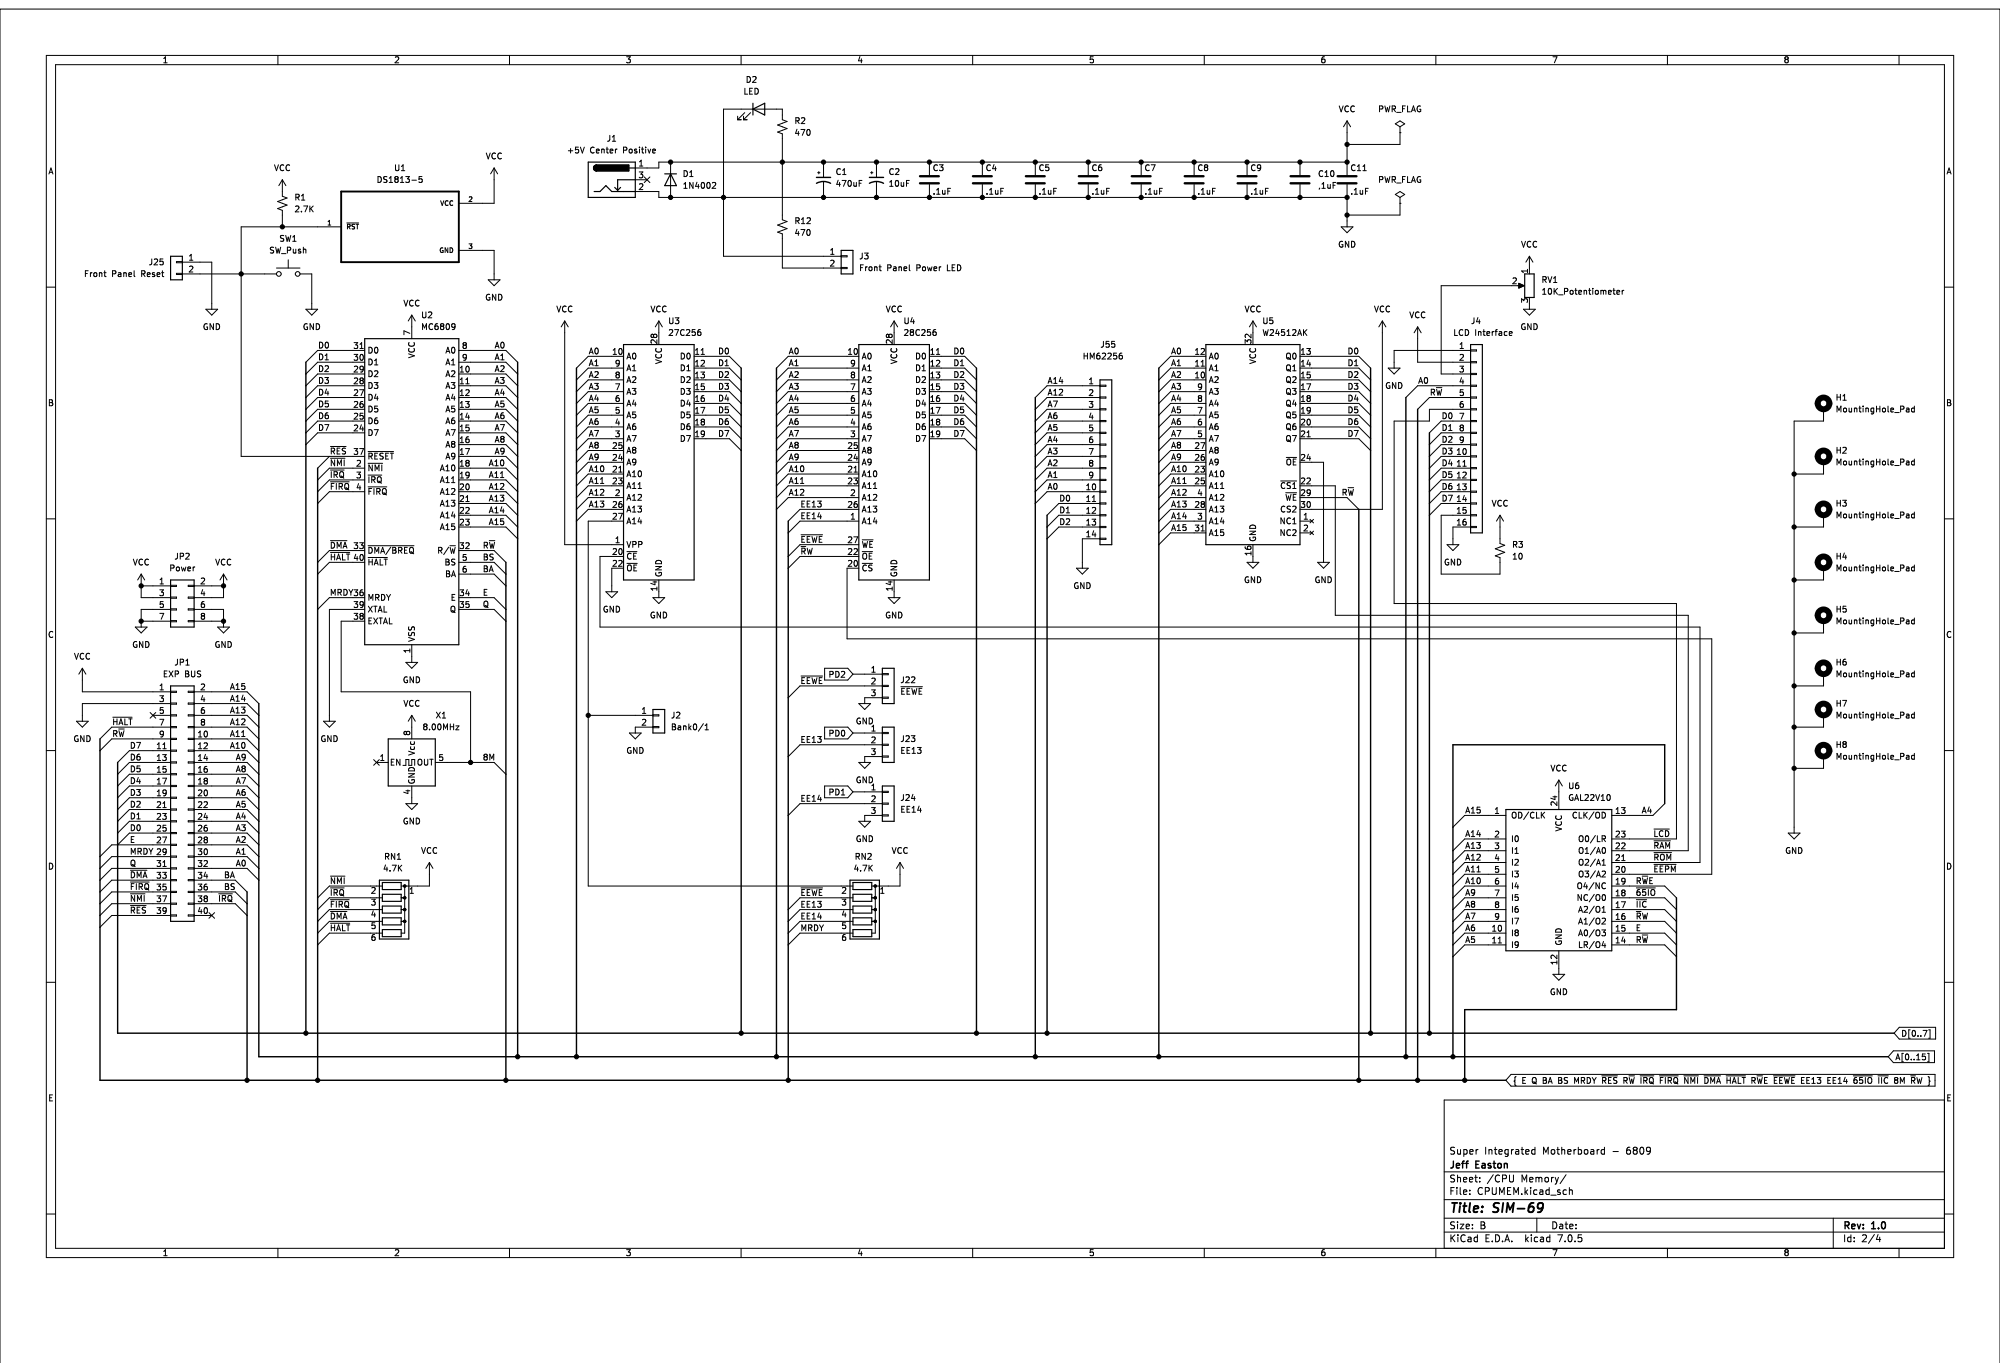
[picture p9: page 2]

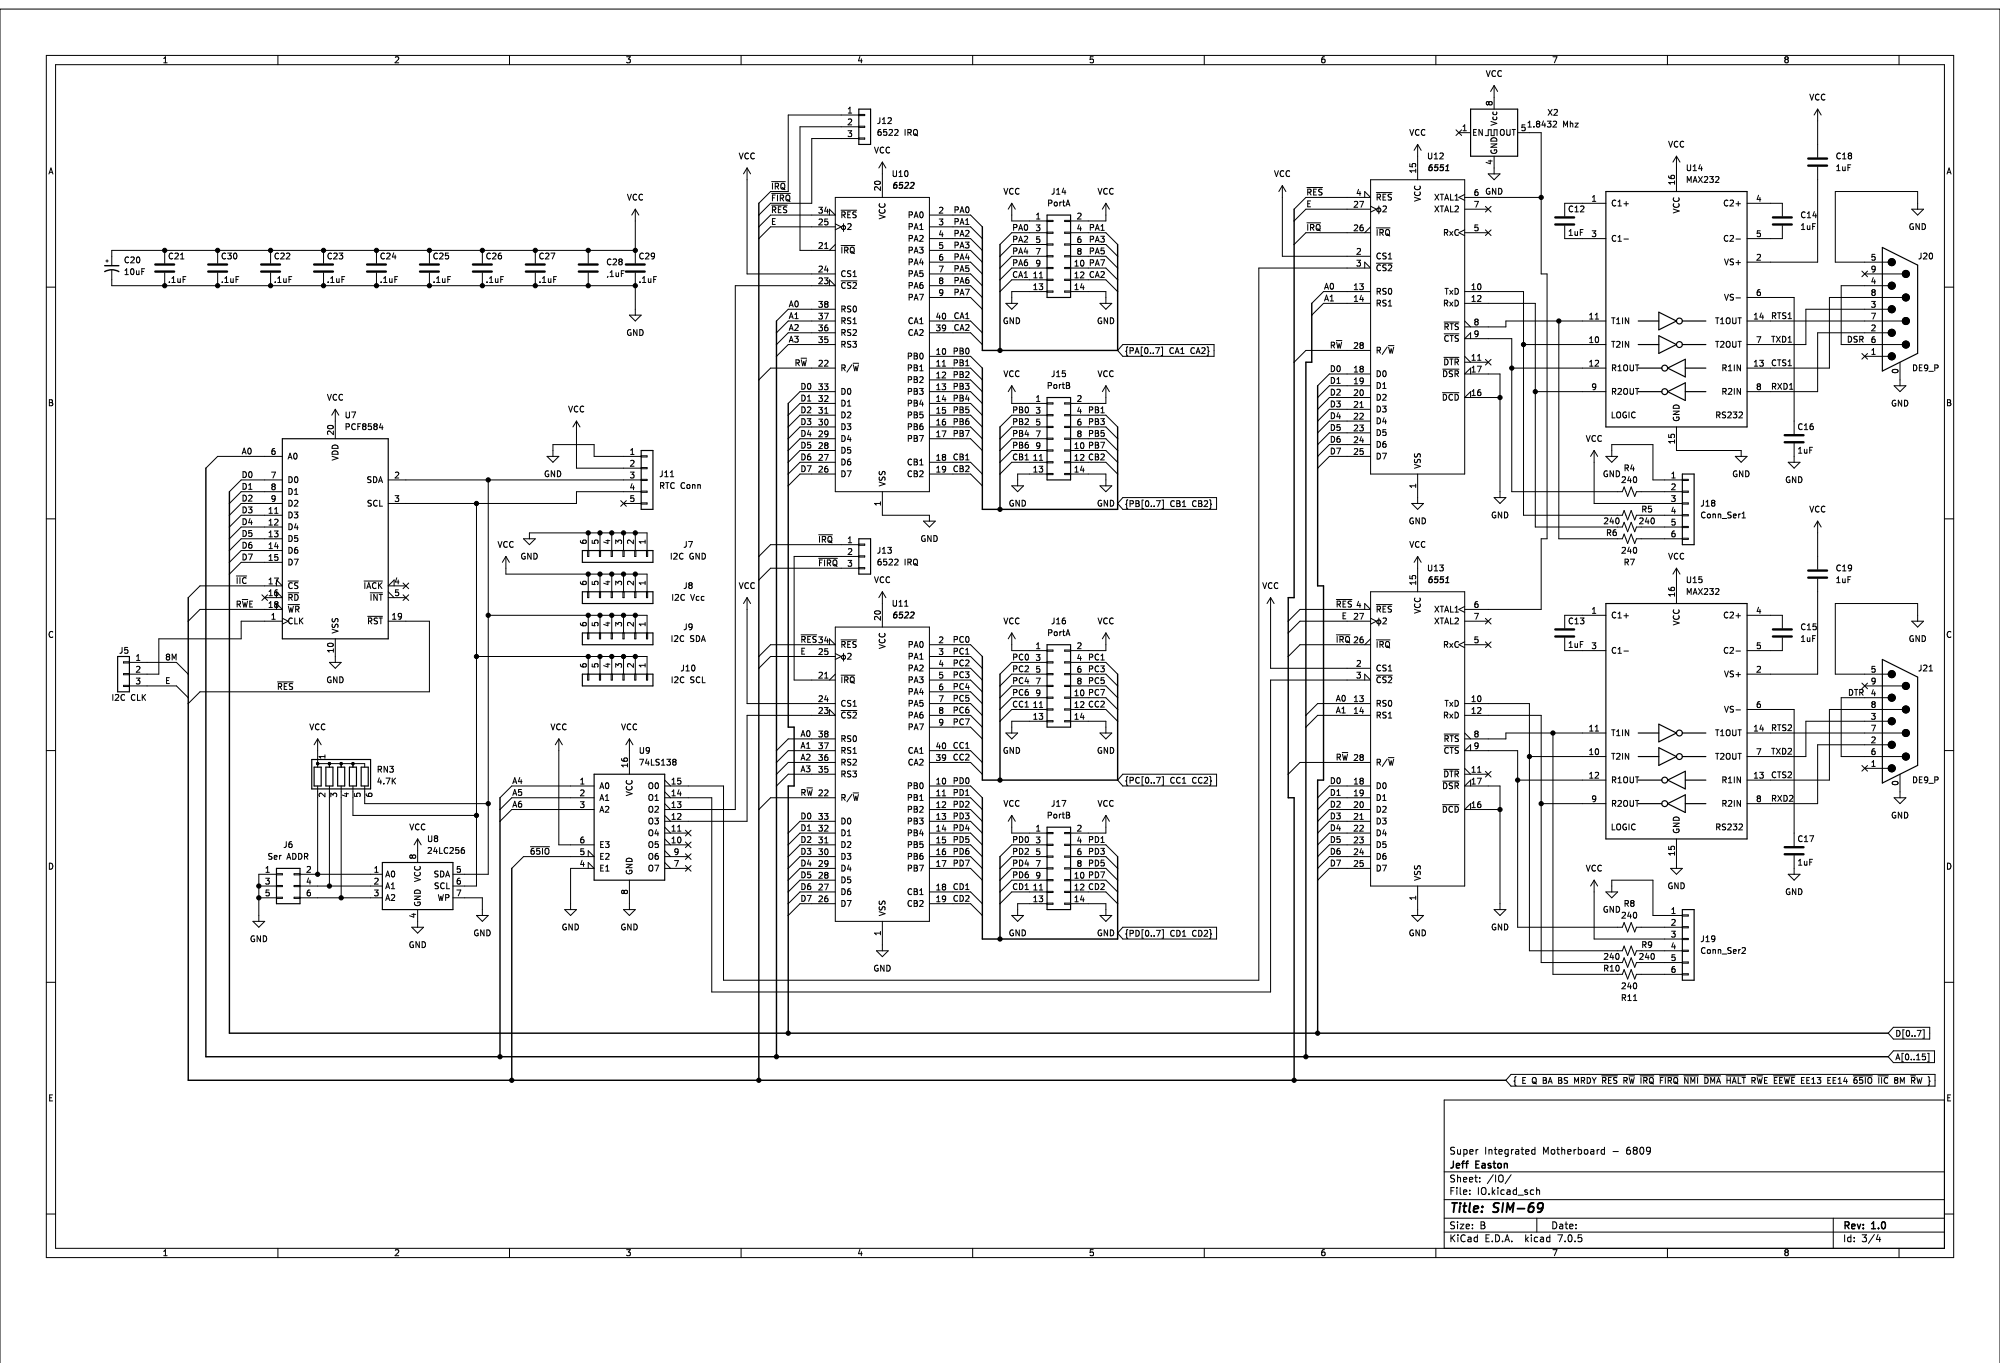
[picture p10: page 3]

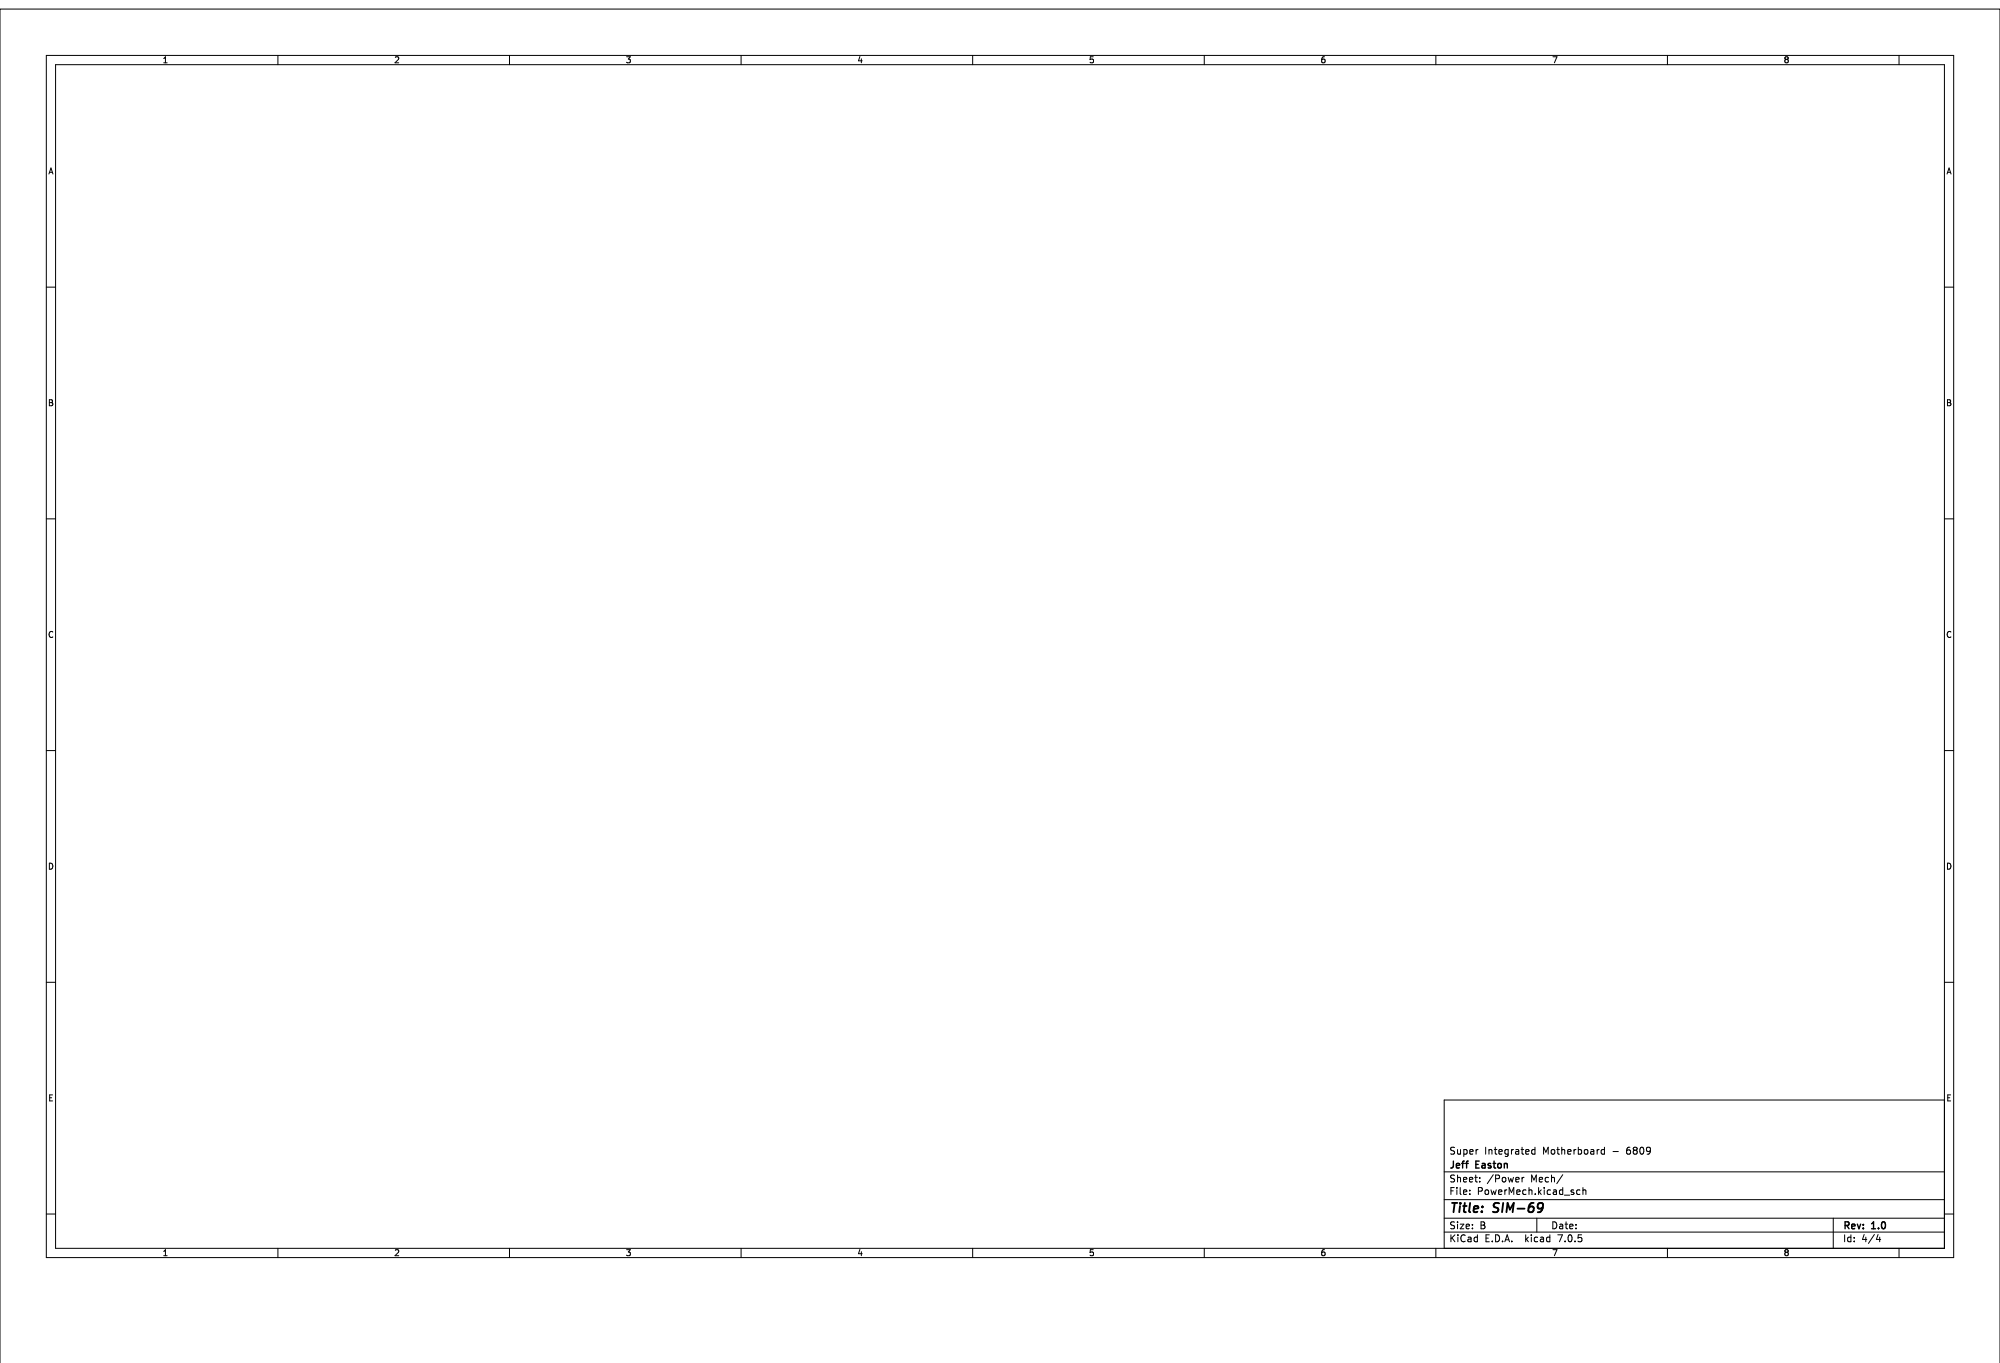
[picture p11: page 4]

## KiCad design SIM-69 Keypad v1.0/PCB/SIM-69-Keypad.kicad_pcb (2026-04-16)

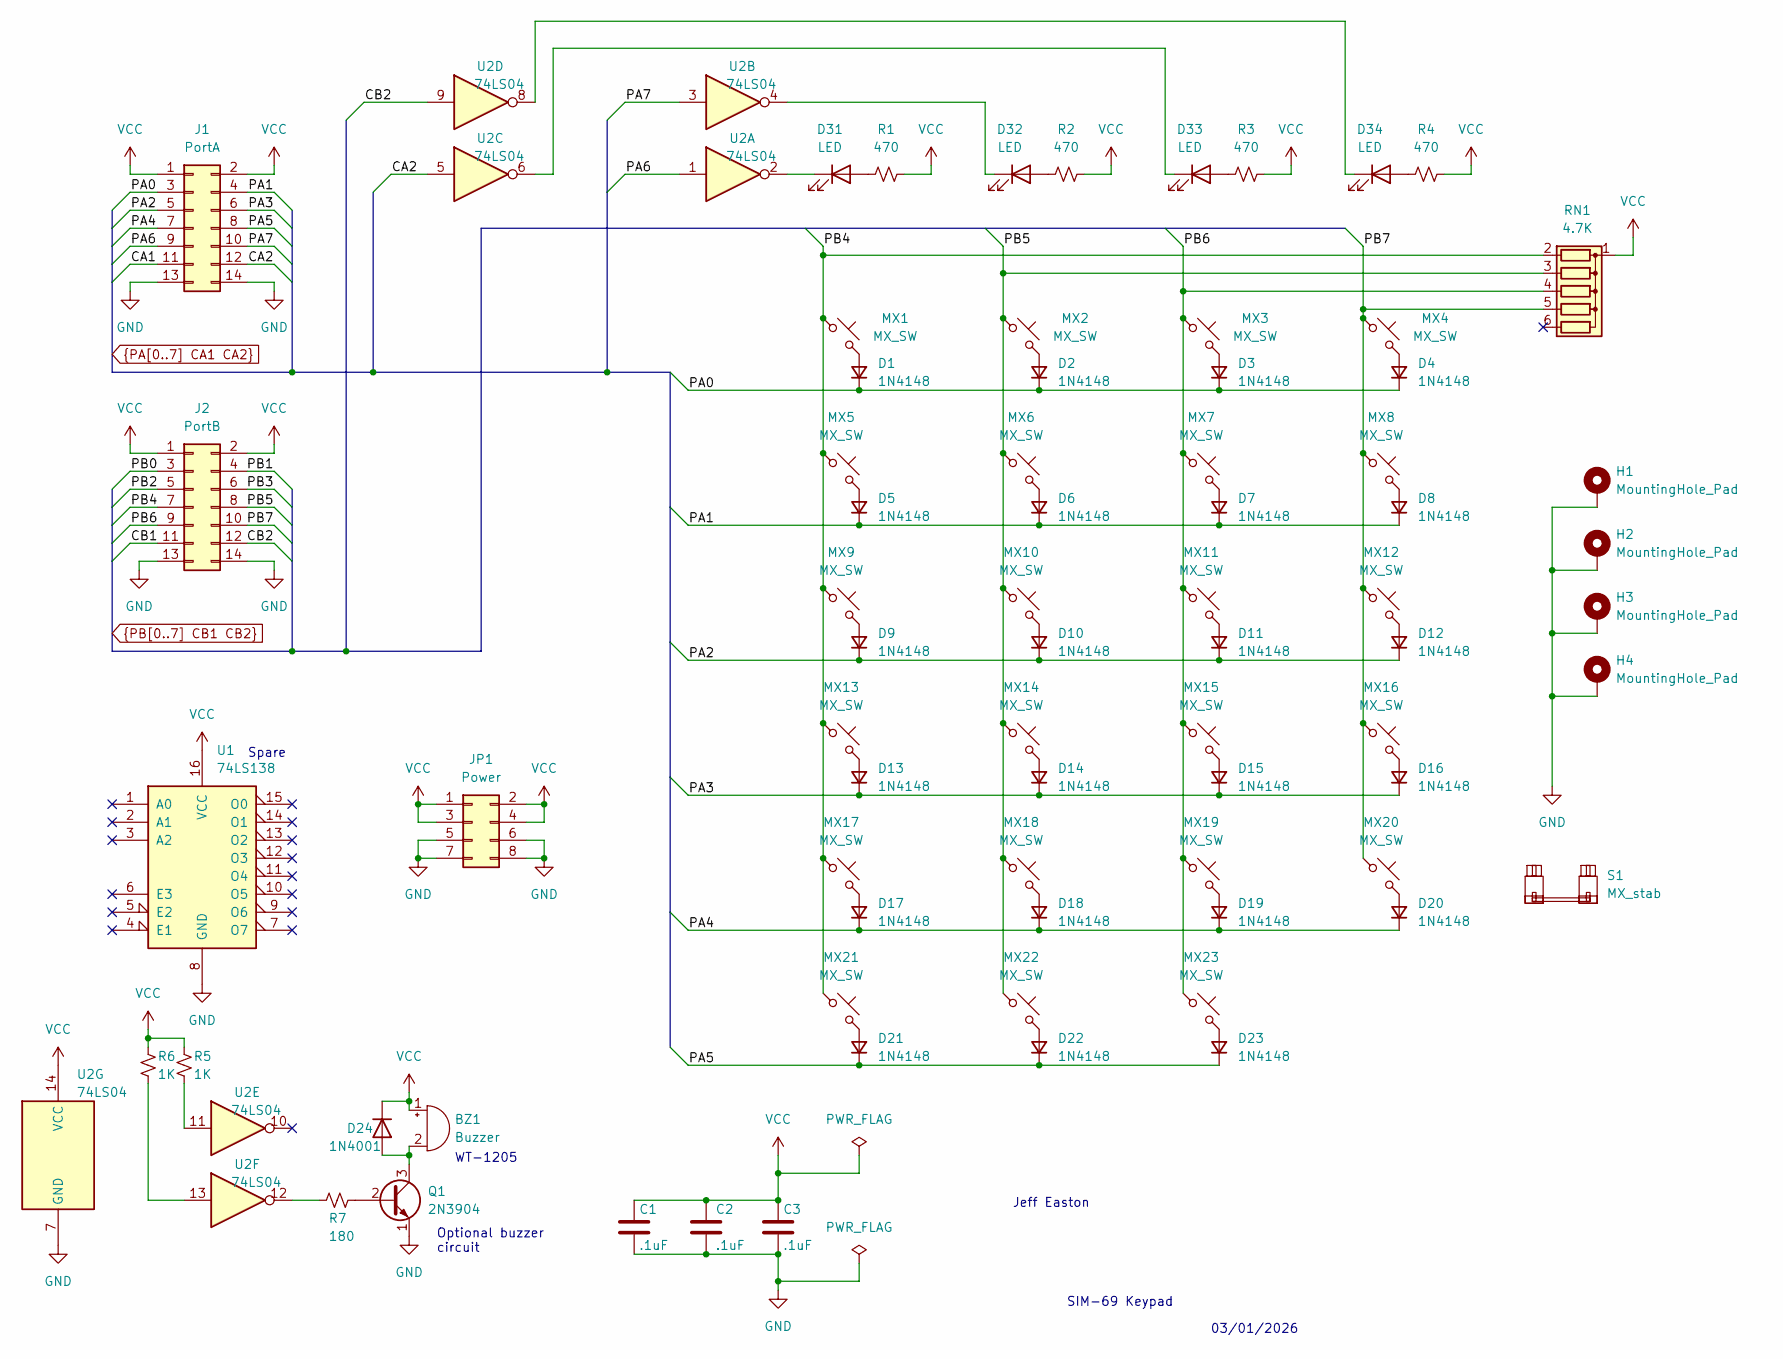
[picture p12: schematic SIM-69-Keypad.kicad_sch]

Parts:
BZ1: Buzzer; Buzzer_TDK_PS1240P02BT_D12.2mm_H6.5mm
C1, C2, C3: .1uF; C_Rect_L7.0mm_W2.0mm_P5.00mm
D1, D2, D3, D4, D5, D6, D7, D8, D9, D10, D11, D12, D13, D14, D15, D16, D17, D18, D19, D20, D21, D22, D23: 1N4148; D_DO-35_SOD27_P7.62mm_Horizontal
D24: 1N4001; D_DO-41_SOD81_P10.16mm_Horizontal
D31, D32, D33, D34: LED; LED_D3.0mm
H1, H2, H3, H4: MountingHole_Pad; MountingHole_3.7mm_Pad_TopBottom
J1: PortA; PinHeader_2x07_P2.54mm_Vertical
J2: PortB; PinHeader_2x07_P2.54mm_Vertical
JP1: Power; PinHeader_2x04_P2.54mm_Vertical
MX1, MX2, MX3, MX4, MX5, MX6, MX7, MX8, MX9, MX10, MX11, MX12, MX13, MX14, MX15, MX16, MX17, MX18, MX19, MX20, MX21, MX22, MX23: MX_SW; SW_MX_1u
Q1: 2N3904; TO-92_Inline
R1, R2, R3, R4: 470; R_Axial_DIN0207_L6.3mm_D2.5mm_P10.16mm_Horizontal
R5, R6: 1K; R_Axial_DIN0207_L6.3mm_D2.5mm_P10.16mm_Horizontal
R7: 180; R_Axial_DIN0207_L6.3mm_D2.5mm_P10.16mm_Horizontal
RN1: 4.7K; R_Array_SIP6
S1: MX_stab; STAB_MX_P_2u
U1: 74LS138; DIP-16_W7.62mm_Socket
U2: 74LS04; DIP-14_W7.62mm_Socket

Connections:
CA1: J1.11
CA2: J1.12, U2.5
CB1: J2.11
CB2: J2.12, U2.9
GND: C1.2, C2.2, C3.2, H1.1, H2.1, H3.1, H4.1, J1.13, J1.14, J2.13, J2.14, JP1.5, JP1.6, JP1.7, JP1.8, Q1.1 (E), U1.8 (GND), U2.7 (GND)
unnamed: BZ1.2 (+), D24.2 (A), Q1.3 (C)
unnamed: D1.2 (A), MX1.2
unnamed: D2.2 (A), MX2.2
unnamed: D3.2 (A), MX3.2
unnamed: D4.2 (A), MX4.2
unnamed: D5.2 (A), MX5.2
unnamed: D6.2 (A), MX6.2
unnamed: D7.2 (A), MX7.2
unnamed: D8.2 (A), MX8.2
unnamed: D9.2 (A), MX9.2
unnamed: D10.2 (A), MX10.2
unnamed: D11.2 (A), MX11.2
unnamed: D12.2 (A), MX12.2
unnamed: D13.2 (A), MX13.2
unnamed: D14.2 (A), MX14.2
unnamed: D15.2 (A), MX15.2
unnamed: D16.2 (A), MX16.2
unnamed: D17.2 (A), MX17.2
unnamed: D18.2 (A), MX18.2
unnamed: D19.2 (A), MX19.2
unnamed: D20.2 (A), MX20.2
unnamed: D21.2 (A), MX21.2
unnamed: D22.2 (A), MX22.2
unnamed: D23.2 (A), MX23.2
unnamed: D31.2 (A), R1.1
unnamed: D31.1 (K), U2.2
unnamed: D32.2 (A), R2.1
unnamed: D32.1 (K), U2.4
unnamed: D33.2 (A), R3.1
unnamed: D33.1 (K), U2.6
unnamed: D34.2 (A), R4.1
unnamed: D34.1 (K), U2.8
unnamed: Q1.2 (B), R7.1
unnamed: R5.2, U2.11
unnamed: R6.2, U2.13
unnamed: R7.2, U2.12
PA0: D1.1 (K), D2.1 (K), D3.1 (K), D4.1 (K), J1.3
PA1: D5.1 (K), D6.1 (K), D7.1 (K), D8.1 (K), J1.4
PA2: D9.1 (K), D10.1 (K), D11.1 (K), D12.1 (K), J1.5
PA3: D13.1 (K), D14.1 (K), D15.1 (K), D16.1 (K), J1.6
PA4: D17.1 (K), D18.1 (K), D19.1 (K), D20.1 (K), J1.7
PA5: D21.1 (K), D22.1 (K), D23.1 (K), J1.8
PA6: J1.9, U2.1
PA7: J1.10, U2.3
PB0: J2.3
PB1: J2.4
PB2: J2.5
PB3: J2.6
PB4: J2.7, MX1.1, MX5.1, MX9.1, MX13.1, MX17.1, MX21.1, RN1.2 (R1)
PB5: J2.8, MX2.1, MX6.1, MX10.1, MX14.1, MX18.1, MX22.1, RN1.3 (R2)
PB6: J2.9, MX3.1, MX7.1, MX11.1, MX15.1, MX19.1, MX23.1, RN1.4 (R3)
PB7: J2.10, MX4.1, MX8.1, MX12.1, MX16.1, MX20.1, RN1.5 (R4)
VCC: BZ1.1 (-), C1.1, C2.1, C3.1, D24.1 (K), J1.1, J1.2, J2.1, J2.2, JP1.1, JP1.2, JP1.3, JP1.4, R1.2, R2.2, R3.2, R4.2, R5.1, R6.1, RN1.1 (common), U1.16 (VCC), U2.14 (VCC)

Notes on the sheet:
Jeff Easton
Optional buzzer circuit
Spare
WT-1205
SIM-69 Keypad
03/01/2026

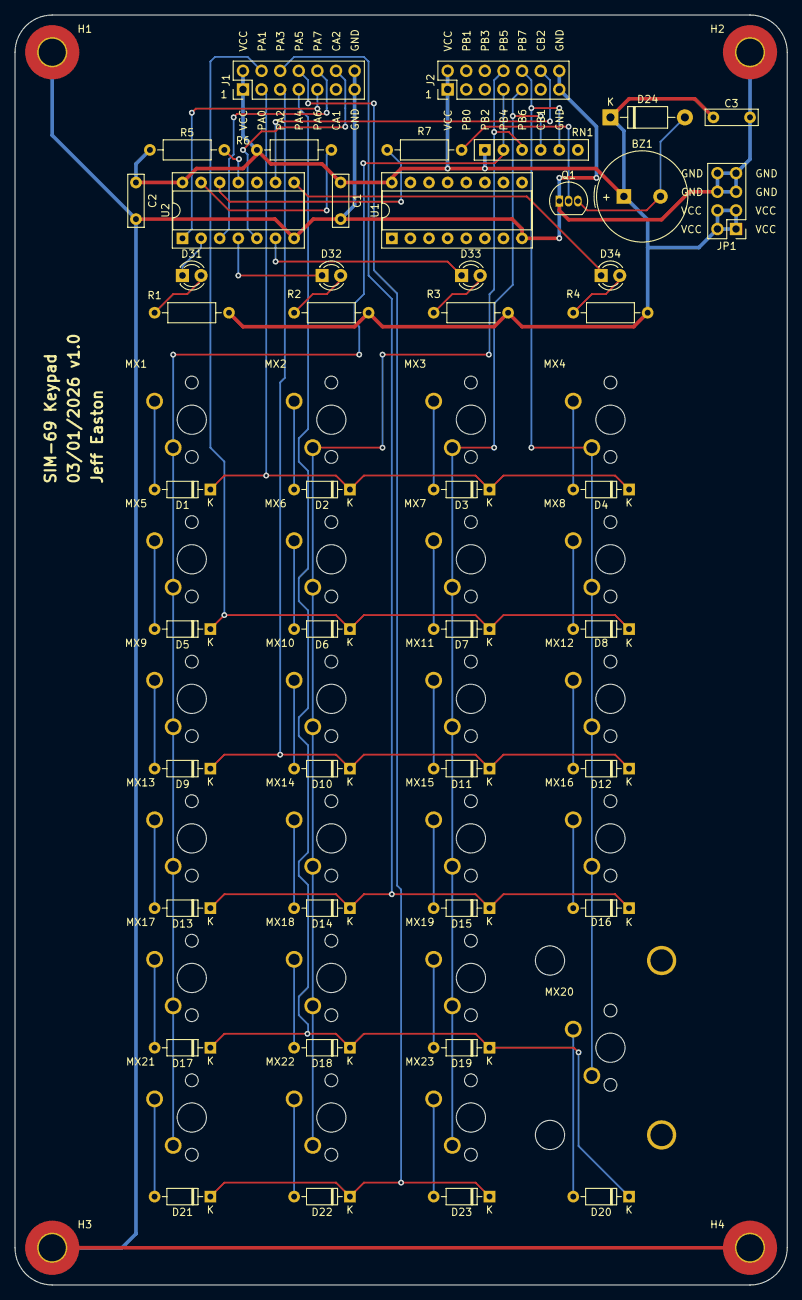
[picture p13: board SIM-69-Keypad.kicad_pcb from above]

Board: 2 copper layers, 105.4 x 173.4 mm, 74 parts (0 on the bottom side), 52 nets.

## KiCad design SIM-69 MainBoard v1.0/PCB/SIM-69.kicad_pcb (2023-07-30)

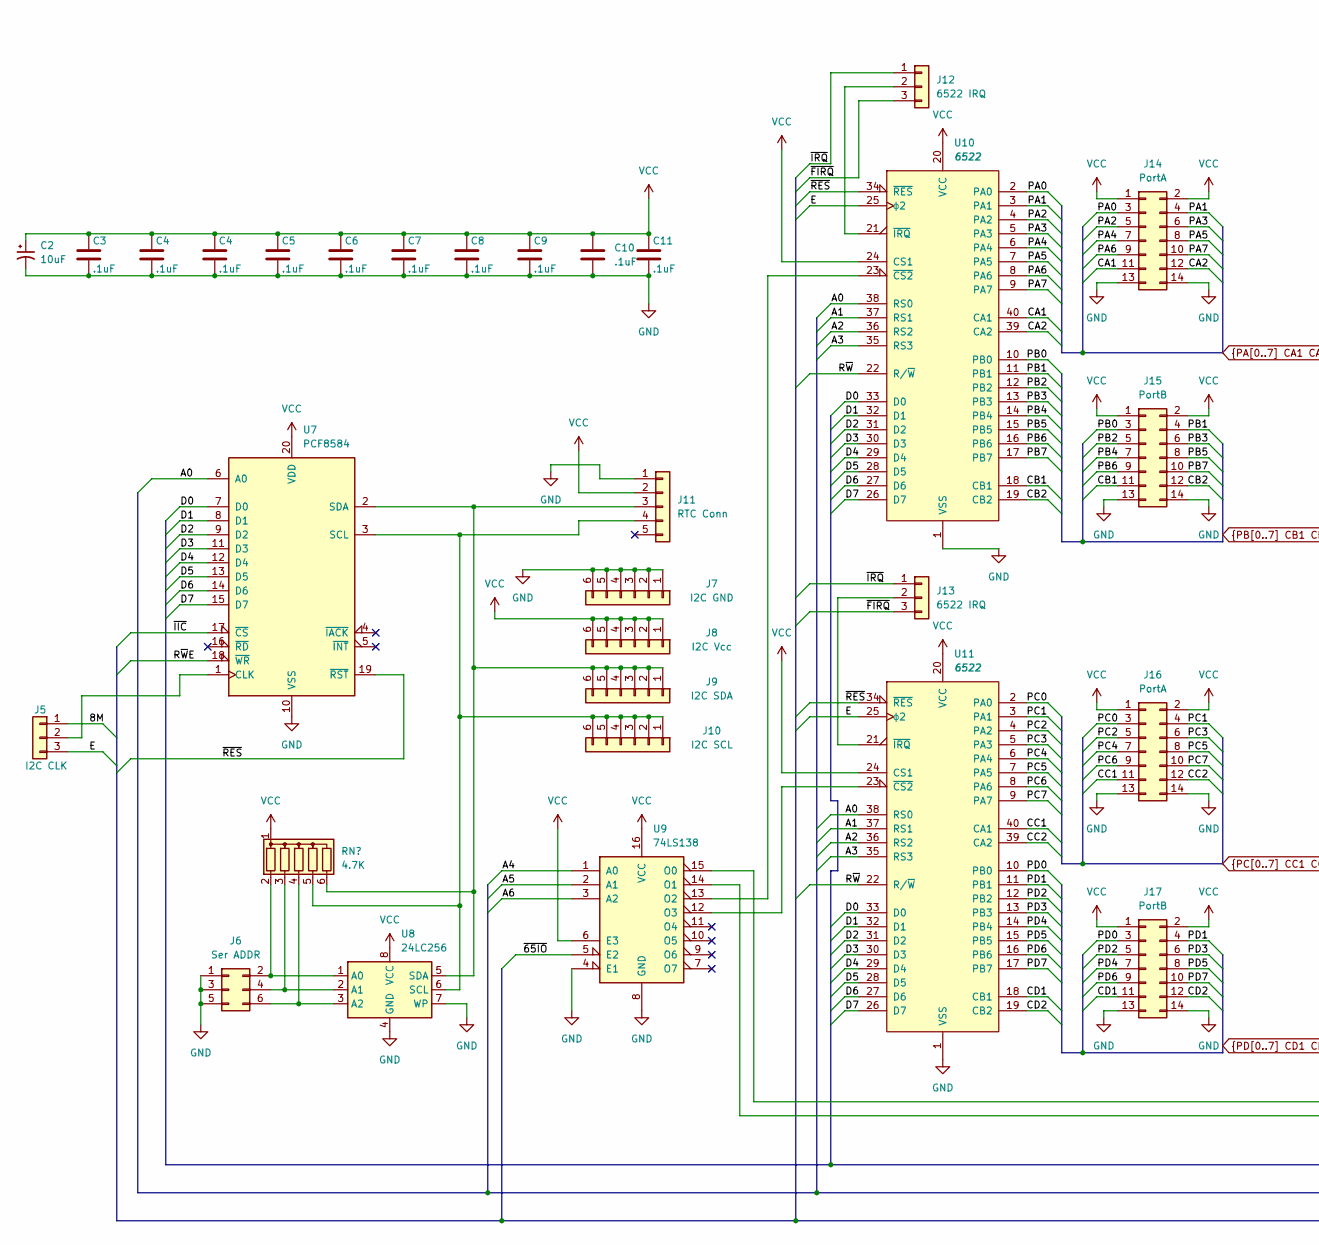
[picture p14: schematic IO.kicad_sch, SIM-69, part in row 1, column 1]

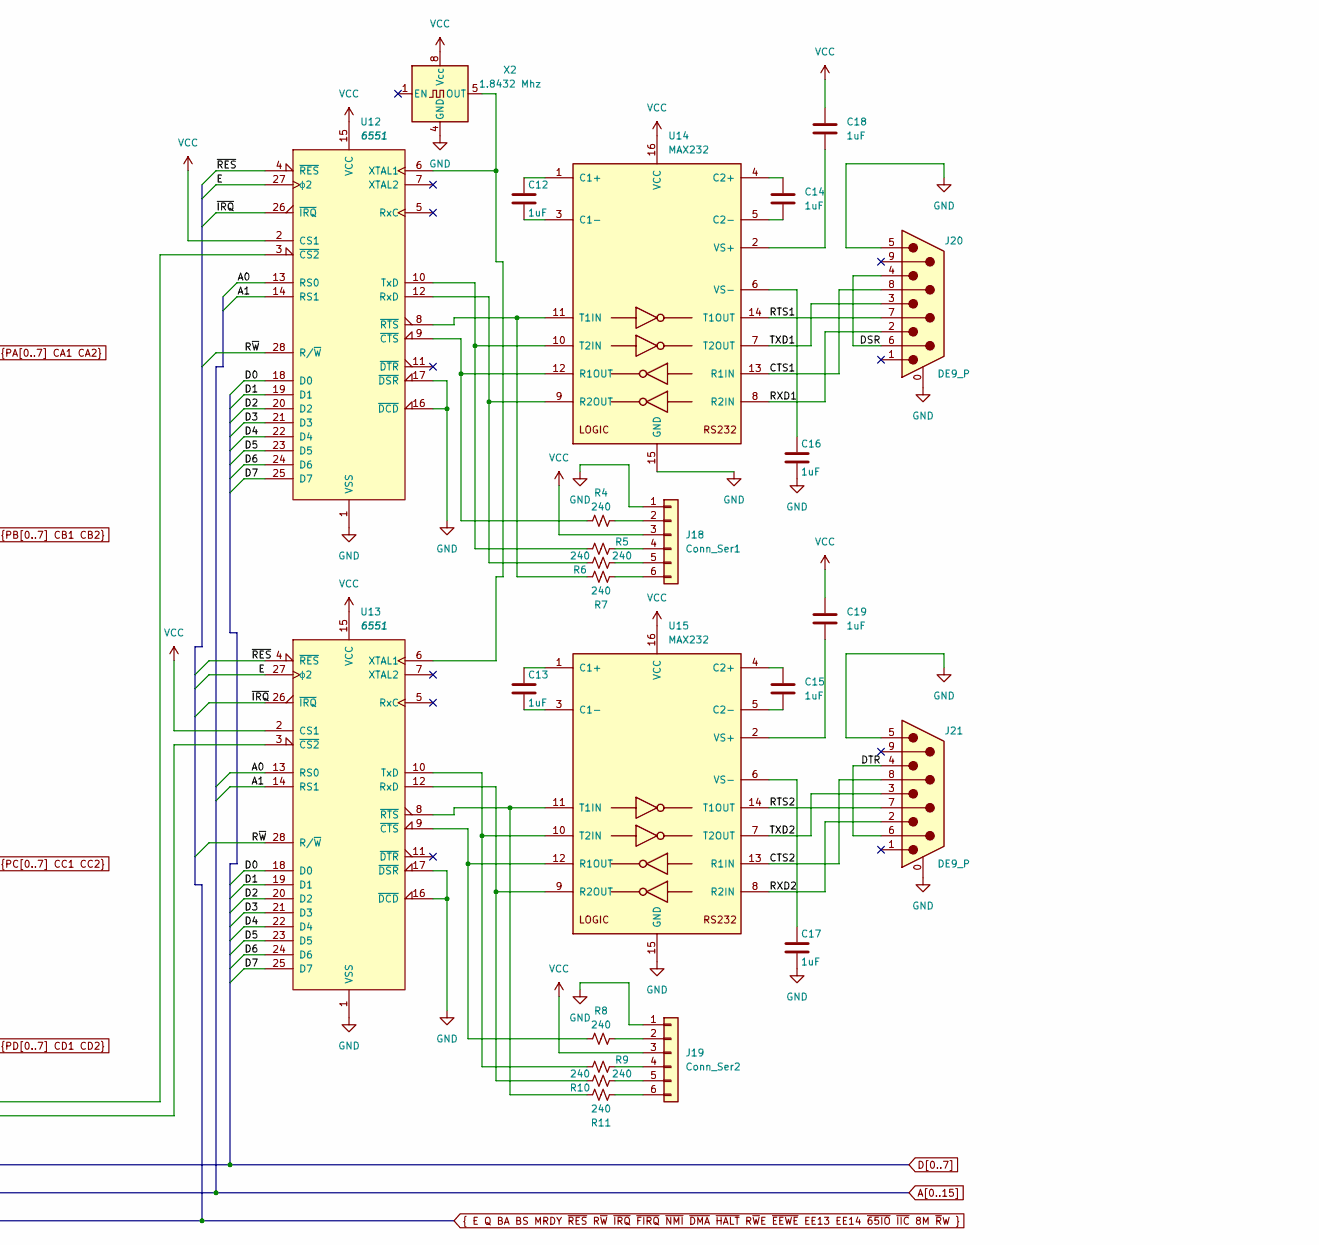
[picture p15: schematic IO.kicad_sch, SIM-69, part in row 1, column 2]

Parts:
C2: 10uF; CP_Radial_Tantal_D4.5mm_P2.50mm
C3, C4, C5, C6, C7, C8, C9, C10, C11: .1uF; C_Rect_L7.0mm_W2.0mm_P5.00mm
C12, C13, C14, C15, C16, C17, C18, C19: 1uF; C_Rect_L7.0mm_W2.0mm_P5.00mm
J5: I2C CLK; PinHeader_1x03_P2.54mm_Vertical
J6: Ser ADDR; PinHeader_2x03_P2.54mm_Vertical
J7: I2C GND; PinSocket_1x06_P2.54mm_Vertical
J8: I2C Vcc; PinSocket_1x06_P2.54mm_Vertical
J9: I2C SDA; PinSocket_1x06_P2.54mm_Vertical
J10: I2C SCL; PinSocket_1x06_P2.54mm_Vertical
J11: RTC Conn; PinHeader_1x05_P2.54mm_Vertical
J12, J13: 6522 IRQ; PinHeader_1x03_P2.54mm_Vertical
J14, J16: PortA; PinHeader_2x07_P2.54mm_Vertical
J15, J17: PortB; PinHeader_2x07_P2.54mm_Vertical
J18: Conn_Ser1; PinHeader_1x06_P2.54mm_Vertical
J19: Conn_Ser2; PinHeader_1x06_P2.54mm_Vertical
J20, J21: DE9_P; DSUB-9_Male_Horizontal_P2.77x2.84mm_EdgePinOffset7.70mm_Hou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
R4, R5, R6, R7, R8, R9, R10, R11: 240; R_Axial_DIN0207_L6.3mm_D2.5mm_P10.16mm_Horizontal
RN3: 4.7K; R_Array_SIP6
U7: PCF8584; DIP-20_W7.62mm
U8: 24LC256; DIP-8_W7.62mm_Socket
U9: 74LS138; DIP-16_W7.62mm_Socket
U10, U11: 6522; DIP-40_W15.24mm_Socket
U12, U13: 6551; DIP-28_W15.24mm_Socket
U14, U15: MAX232; DIP-16_W7.62mm_Socket
X2: 1.8432 Mhz; Oscillator_DIP-8

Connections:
8M: J5.1; also elsewhere on the board
/IO/CTS1: J20.8, U14.13 (R1IN)
/IO/CTS2: J21.8, U15.13 (R1IN)
/IO/DSR: J20.4, J20.6
/IO/DTR: J21.4, J21.6
/IO/RTS1: J20.7, U14.14 (T1OUT)
/IO/RTS2: J21.7, U15.14 (T1OUT)
/IO/RXD1: J20.2, U14.8 (R2IN)
/IO/RXD2: J21.2, U15.8 (R2IN)
/IO/TXD1: J20.3, U14.7 (T2OUT)
/IO/TXD2: J21.3, U15.7 (T2OUT)
A0: U7.6 (A0), U10.38 (RS0), U11.38 (RS0), U12.13 (RS0), U13.13 (RS0); also elsewhere on the board
A1: U10.37 (RS1), U11.37 (RS1), U12.14 (RS1), U13.14 (RS1); also elsewhere on the board
A2: U10.36 (RS2), U11.36 (RS2); also elsewhere on the board
A3: U10.35 (RS3), U11.35 (RS3); also elsewhere on the board
A4: U9.1 (A0); also elsewhere on the board
A5: U9.2 (A1); also elsewhere on the board
A6: U9.3 (A2); also elsewhere on the board
CA1: J14.11, U10.40 (CA1)
CA2: J14.12, U10.39 (CA2)
CB1: J15.11, U10.18 (CB1)
CB2: J15.12, U10.19 (CB2)
CC1: J16.11, U11.40 (CA1)
CC2: J16.12, U11.39 (CA2)
CD1: J17.11, U11.18 (CB1)
CD2: J17.12, U11.19 (CB2)
D0: U7.7 (D0), U10.33 (D0), U11.33 (D0), U12.18 (D0), U13.18 (D0); also elsewhere on the board
D1: U7.8 (D1), U10.32 (D1), U11.32 (D1), U12.19 (D1), U13.19 (D1); also elsewhere on the board
D2: U7.9 (D2), U10.31 (D2), U11.31 (D2), U12.20 (D2), U13.20 (D2); also elsewhere on the board
D3: U7.11 (D3), U10.30 (D3), U11.30 (D3), U12.21 (D3), U13.21 (D3); also elsewhere on the board
D4: U7.12 (D4), U10.29 (D4), U11.29 (D4), U12.22 (D4), U13.22 (D4); also elsewhere on the board
D5: U7.13 (D5), U10.28 (D5), U11.28 (D5), U12.23 (D5), U13.23 (D5); also elsewhere on the board
D6: U7.14 (D6), U10.27 (D6), U11.27 (D6), U12.24 (D6), U13.24 (D6); also elsewhere on the board
D7: U7.15 (D7), U10.26 (D7), U11.26 (D7), U12.25 (D7), U13.25 (D7); also elsewhere on the board
E: J5.3, U10.25 (ϕ2), U11.25 (ϕ2), U12.27 (ϕ2), U13.27 (ϕ2); also elsewhere on the board
unnamed: J5.2, U7.1 (CLK)
unnamed: J6.2, RN3.2 (R1), U8.1 (A0)
unnamed: J6.4, RN3.3 (R2), U8.2 (A1)
unnamed: J6.6, RN3.4 (R3), U8.3 (A2)
unnamed: J10.1, J10.2, J10.3, J10.4, J10.5, J10.6, J11.4, RN3.5 (R4), U7.3 (SCL), U8.6 (SCL)
unnamed: J9.1, J9.2, J9.3, J9.4, J9.5, J9.6, J11.3, RN3.6 (R5), U7.2 (SDA), U8.5 (SDA)
unnamed: J12.2, U10.21 (~IRQ)
unnamed: J18.2, R4.2
unnamed: J18.4, R5.2
unnamed: J18.5, R6.2
unnamed: J18.6, R7.2
unnamed: J19.2, R8.2
unnamed: J19.4, R9.2
unnamed: J19.5, R10.2
unnamed: J19.6, R11.2
unnamed: U9.13 (O2), U10.23 (~CS2)
unnamed: U9.12 (O3), U11.23 (~CS2)
unnamed: R6.1, U12.12 (RxD), U14.9 (R2OUT)
unnamed: R5.1, U12.10 (TxD), U14.10 (T2IN)
unnamed: U12.6 (XTAL1), U13.6 (XTAL1), X2.5 (OUT)
unnamed: U9.15 (O0), U12.3 (~CS2)
unnamed: R4.1, U12.9 (~CTS), U14.12 (R1OUT)
unnamed: R7.1, U12.8 (~RTS), U14.11 (T1IN)
unnamed: R10.1, U13.12 (RxD), U15.9 (R2OUT)
unnamed: R9.1, U13.10 (TxD), U15.10 (T2IN)
unnamed: U9.14 (O1), U13.3 (~CS2)
unnamed: R8.1, U13.9 (~CTS), U15.12 (R1OUT)
unnamed: R11.1, U13.8 (~RTS), U15.11 (T1IN)
unnamed: C12.1, U14.1 (C1+)
unnamed: C12.2, U14.3 (C1-)
unnamed: C14.1, U14.4 (C2+)
unnamed: C14.2, U14.5 (C2-)
unnamed: C18.2, U14.2 (VS+)
unnamed: C16.1, U14.6 (VS-)
unnamed: C13.1, U15.1 (C1+)
unnamed: C13.2, U15.3 (C1-)
unnamed: C15.1, U15.4 (C2+)
unnamed: C15.2, U15.5 (C2-)
unnamed: C19.2, U15.2 (VS+)
unnamed: C17.1, U15.6 (VS-)
PA0: J14.3, U10.2 (PA0)
PA1: J14.4, U10.3 (PA1)
PA2: J14.5, U10.4 (PA2)
PA3: J14.6, U10.5 (PA3)
PA4: J14.7, U10.6 (PA4)
PA5: J14.8, U10.7 (PA5)
PA6: J14.9, U10.8 (PA6)
PA7: J14.10, U10.9 (PA7)
PB0: J15.3, U10.10 (PB0)
PB1: J15.4, U10.11 (PB1)
PB2: J15.5, U10.12 (PB2)
PB3: J15.6, U10.13 (PB3)
PB4: J15.7, U10.14 (PB4)
PB5: J15.8, U10.15 (PB5)
PB6: J15.9, U10.16 (PB6)
PB7: J15.10, U10.17 (PB7)
PC0: J16.3, U11.2 (PA0)
PC1: J16.4, U11.3 (PA1)
PC2: J16.5, U11.4 (PA2)
PC3: J16.6, U11.5 (PA3)
PC4: J16.7, U11.6 (PA4)
PC5: J16.8, U11.7 (PA5)
PC6: J16.9, U11.8 (PA6)
PC7: J16.10, U11.9 (PA7)
PD0: J17.3, U11.10 (PB0); also elsewhere on the board
PD1: J17.4, U11.11 (PB1); also elsewhere on the board
PD2: J17.5, U11.12 (PB2); also elsewhere on the board
PD3: J17.6, U11.13 (PB3)
PD4: J17.7, U11.14 (PB4)
PD5: J17.8, U11.15 (PB5)
PD6: J17.9, U11.16 (PB6)
PD7: J17.10, U11.17 (PB7)
R~W: U10.22 (R/~W), U11.22 (R/~W), U12.28 (R/~W), U13.28 (R/~W); also elsewhere on the board
R~WE: U7.18 (~WR); also elsewhere on the board
VCC: C2.1, C3.1, C4.1, C5.1, C6.1, C7.1, C8.1, C9.1, C10.1, C11.1, C18.1, C19.1, J8.1, J8.2, J8.3, J8.4, J8.5, J8.6, J11.2, J14.1, J14.2, J15.1, J15.2, J16.1, J16.2, J17.1, J17.2, J18.3, J19.3, RN3.1 (common), U7.20 (VDD), U8.8 (VCC), U9.6 (E3), U9.16 (VCC), U10.20 (VCC), U10.24 (CS1), U11.20 (VCC), U11.24 (CS1), U12.2 (CS1), U12.15 (VCC), U13.2 (CS1), U13.15 (VCC), U14.16 (VCC), U15.16 (VCC), X2.8 (Vcc); also elsewhere on the board
~65IO: U9.5 (E2); also elsewhere on the board
~IIC: U7.17 (~CS); also elsewhere on the board
~RES: U7.19 (~RST), U10.34 (~RES), U11.34 (~RES), U12.4 (~RES), U13.4 (~RES); also elsewhere on the board

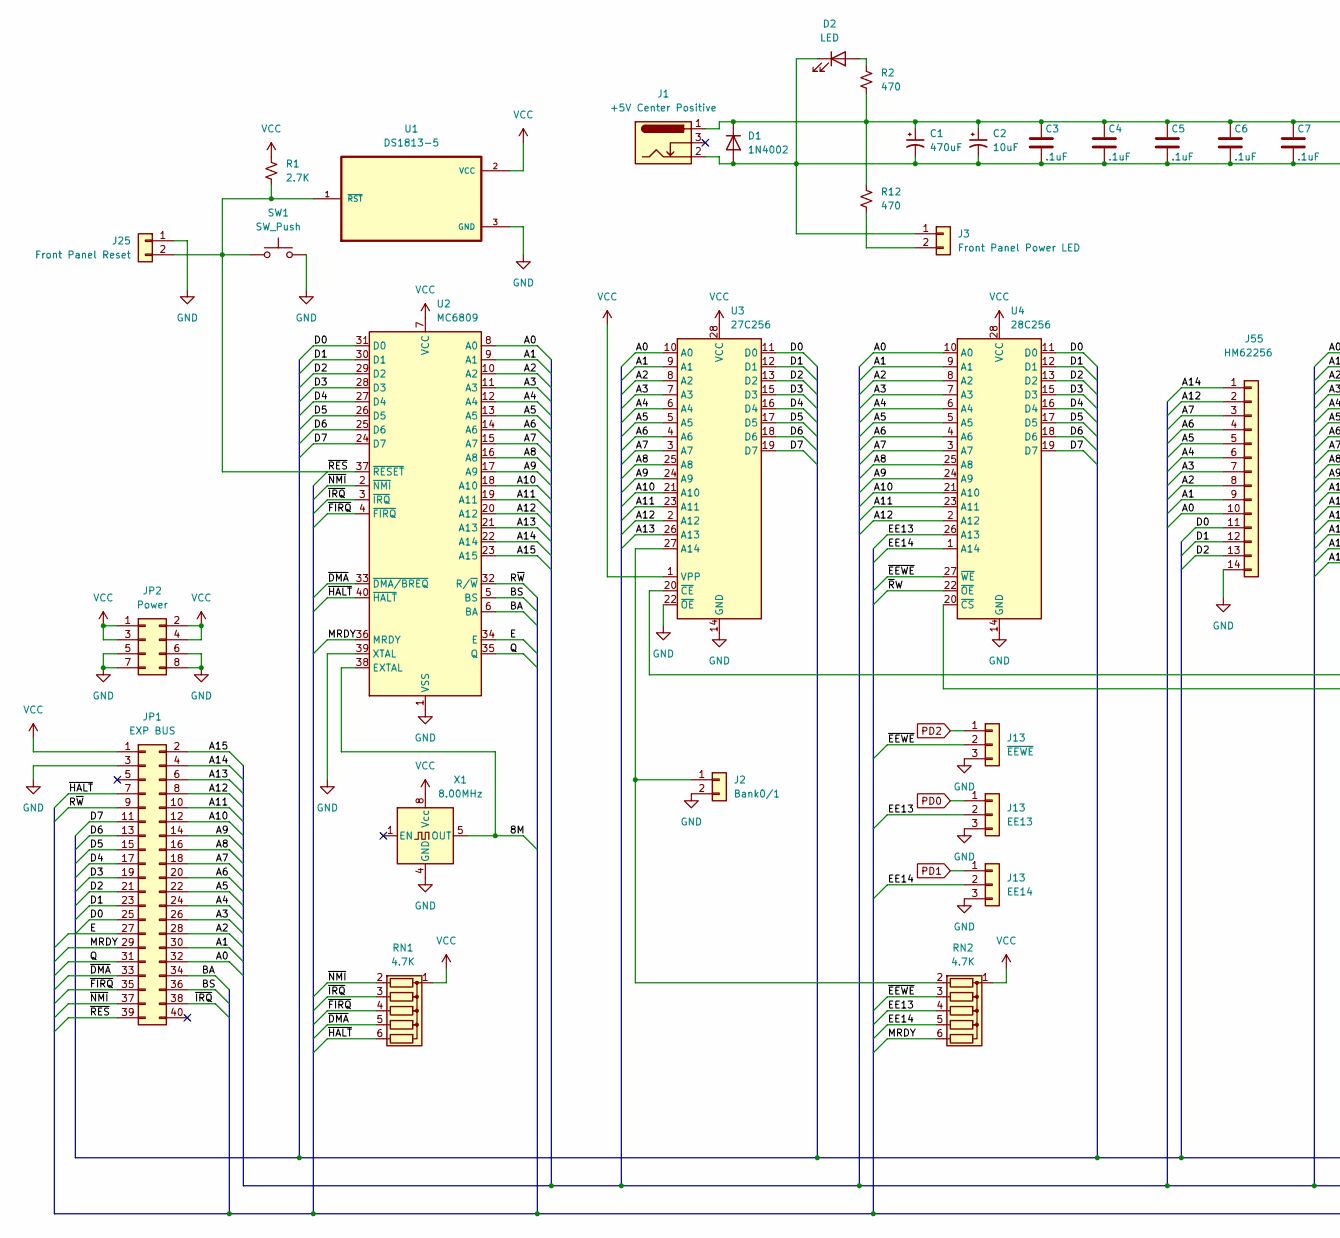
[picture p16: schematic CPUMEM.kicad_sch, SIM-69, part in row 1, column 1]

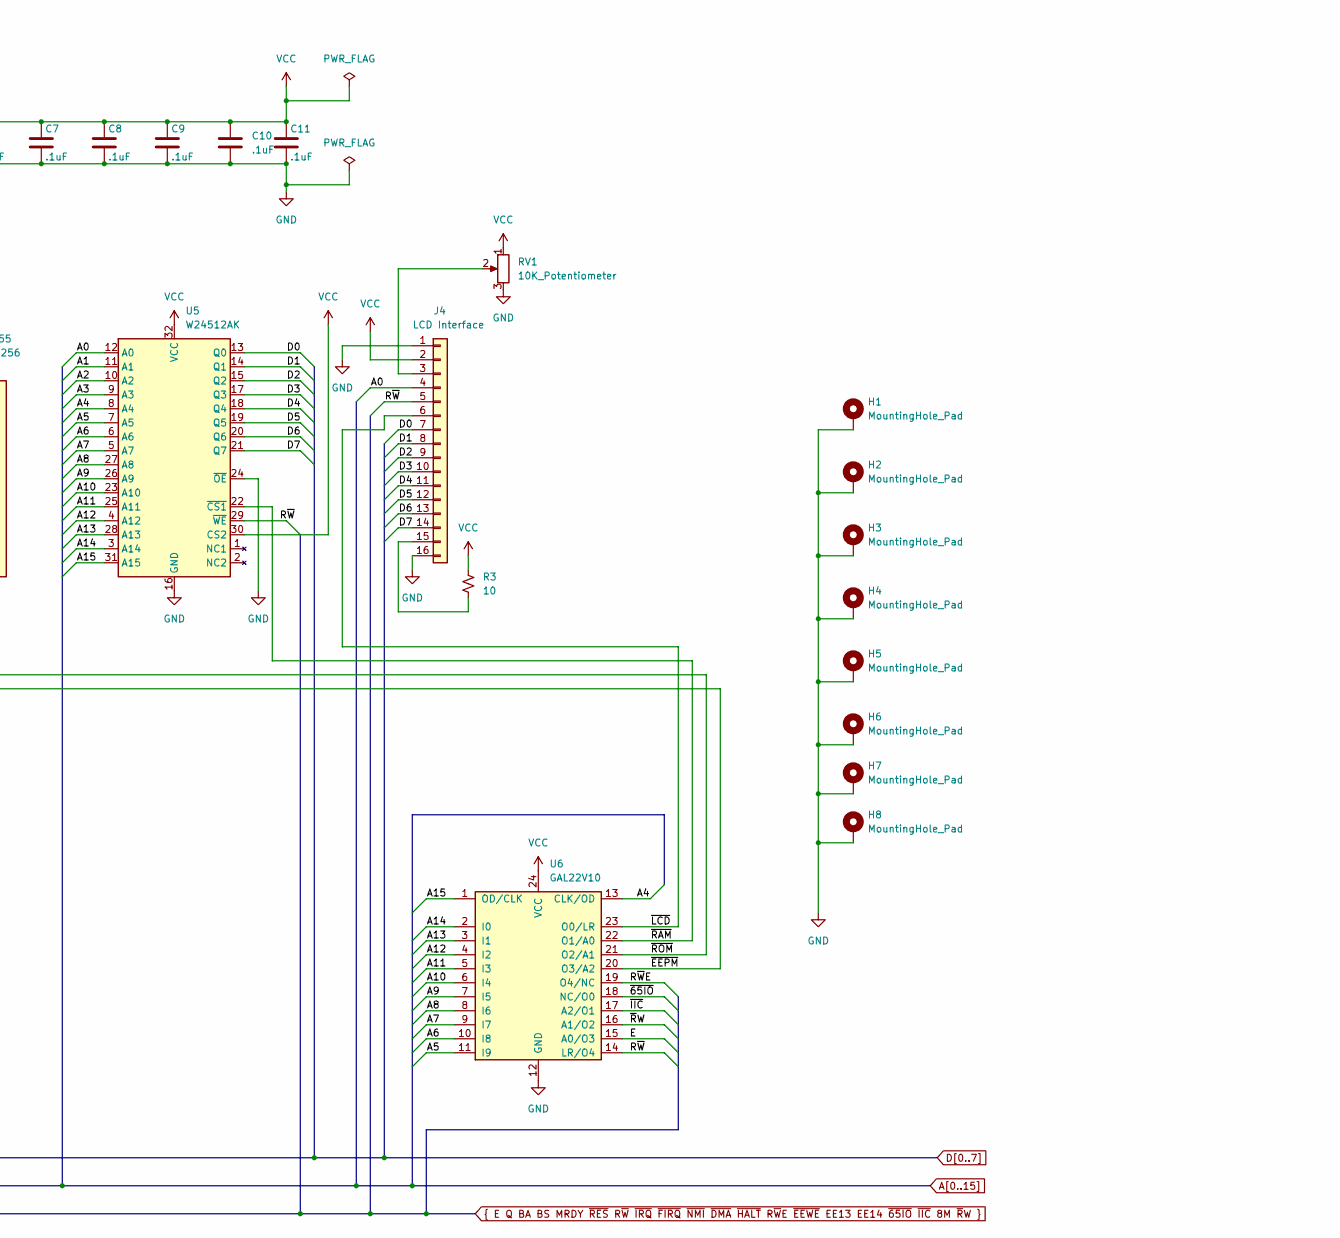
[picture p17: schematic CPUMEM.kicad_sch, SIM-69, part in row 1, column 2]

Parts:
C1: 470uF; CP_Radial_D5.0mm_P2.50mm
C2: 10uF; CP_Radial_Tantal_D4.5mm_P2.50mm
C3, C4, C5, C6, C7, C8, C9, C10, C11: .1uF; C_Rect_L7.0mm_W2.0mm_P5.00mm
D1: 1N4002; D_DO-41_SOD81_P10.16mm_Horizontal
D2: LED; LED_D3.0mm
H1, H2, H3, H4, H5, H6, H7, H8: MountingHole_Pad; MountingHole_3.7mm_Pad_TopBottom
J1: +5V Center Positive; BarrelJack_Horizontal
J2: Bank0/1; PinSocket_1x02_P2.54mm_Vertical
J3: Front Panel Power LED; PinSocket_1x02_P2.54mm_Vertical
J4: LCD Interface; PinSocket_1x16_P2.54mm_Vertical
J13: EE14; PinHeader_1x03_P2.54mm_Vertical
J25: Front Panel Reset; PinSocket_1x02_P2.54mm_Vertical
J55: HM62256; PinSocket_1x14_P2.54mm_Vertical
JP1: EXP BUS; IDC-Header_2x20_P2.54mm_Vertical
JP2: Power; IDC-Header_2x04_P2.54mm_Vertical
R1: 2.7K; R_Axial_DIN0207_L6.3mm_D2.5mm_P10.16mm_Horizontal
R2, R12: 470; R_Axial_DIN0207_L6.3mm_D2.5mm_P10.16mm_Horizontal
R3: 10; R_Axial_DIN0207_L6.3mm_D2.5mm_P10.16mm_Horizontal
RN1, RN2: 4.7K; R_Array_SIP6
RV1: 10K_Potentiometer; Potentiometer_Vishay_T73YP_Vertical
SW1: SW_Push; SW_Tactile_SPST_Angled_PTS645Vx58-2LFS
U1: DS1813-5; TO-92
U2: MC6809; DIP-40_W15.24mm_Socket
U3: 27C256; DIP-28_W15.24mm_Socket
U4: 28C256; DIP-28_W15.24mm_Socket
U5: W24512AK; DIP-32_W7.62mm
U6: GAL22V10; DIP-24_W7.62mm_Socket
X1: 8.00MHz; Oscillator_DIP-8

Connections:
8M: U2.38 (EXTAL), X1.5 (OUT); also elsewhere on the board
/CPU Memory/~EEPM: U4.20 (~CS), U6.20 (O3/A2)
/CPU Memory/~LCD: J4.6, U6.23 (O0/LR)
/CPU Memory/~RAM: U5.22 (~CS1), U6.22 (O1/A0)
/CPU Memory/~ROM: U3.20 (~CE), U6.21 (O2/A1)
A0: J4.4, J55.10, JP1.32, U2.8 (A0), U3.10 (A0), U4.10 (A0), U5.12 (A0); also elsewhere on the board
A1: J55.9, JP1.30, U2.9 (A1), U3.9 (A1), U4.9 (A1), U5.11 (A1); also elsewhere on the board
A2: J55.8, JP1.28, U2.10 (A2), U3.8 (A2), U4.8 (A2), U5.10 (A2); also elsewhere on the board
A3: J55.7, JP1.26, U2.11 (A3), U3.7 (A3), U4.7 (A3), U5.9 (A3); also elsewhere on the board
A4: J55.6, JP1.24, U2.12 (A4), U3.6 (A4), U4.6 (A4), U5.8 (A4), U6.13 (CLK/OD); also elsewhere on the board
A5: J55.5, JP1.22, U2.13 (A5), U3.5 (A5), U4.5 (A5), U5.7 (A5), U6.11 (I9); also elsewhere on the board
A6: J55.4, JP1.20, U2.14 (A6), U3.4 (A6), U4.4 (A6), U5.6 (A6), U6.10 (I8); also elsewhere on the board
A7: J55.3, JP1.18, U2.15 (A7), U3.3 (A7), U4.3 (A7), U5.5 (A7), U6.9 (I7)
A8: JP1.16, U2.16 (A8), U3.25 (A8), U4.25 (A8), U5.27 (A8), U6.8 (I6)
A9: JP1.14, U2.17 (A9), U3.24 (A9), U4.24 (A9), U5.26 (A9), U6.7 (I5)
A10: JP1.12, U2.18 (A10), U3.21 (A10), U4.21 (A10), U5.23 (A10), U6.6 (I4)
A11: JP1.10, U2.19 (A11), U3.23 (A11), U4.23 (A11), U5.25 (A11), U6.5 (I3)
A12: J55.2, JP1.8, U2.20 (A12), U3.2 (A12), U4.2 (A12), U5.4 (A12), U6.4 (I2)
A13: JP1.6, U2.21 (A13), U3.26 (A13), U5.28 (A13), U6.3 (I1)
A14: J55.1, JP1.4, U2.22 (A14), U5.3 (A14), U6.2 (I0)
A15: JP1.2, U2.23 (A15), U5.31 (A15), U6.1 (OD/CLK)
BA: JP1.34, U2.6 (BA)
BS: JP1.36, U2.5 (BS)
D0: J4.7, J55.11, JP1.25, U2.31 (D0), U3.11 (D0), U4.11 (D0), U5.13 (Q0); also elsewhere on the board
D1: J4.8, J55.12, JP1.23, U2.30 (D1), U3.12 (D1), U4.12 (D1), U5.14 (Q1); also elsewhere on the board
D2: J4.9, J55.13, JP1.21, U2.29 (D2), U3.13 (D2), U4.13 (D2), U5.15 (Q2); also elsewhere on the board
D3: J4.10, JP1.19, U2.28 (D3), U3.15 (D3), U4.15 (D3), U5.17 (Q3); also elsewhere on the board
D4: J4.11, JP1.17, U2.27 (D4), U3.16 (D4), U4.16 (D4), U5.18 (Q4); also elsewhere on the board
D5: J4.12, JP1.15, U2.26 (D5), U3.17 (D5), U4.17 (D5), U5.19 (Q5); also elsewhere on the board
D6: J4.13, JP1.13, U2.25 (D6), U3.18 (D6), U4.18 (D6), U5.20 (Q6); also elsewhere on the board
D7: J4.14, JP1.11, U2.24 (D7), U3.19 (D7), U4.19 (D7), U5.21 (Q7); also elsewhere on the board
E: JP1.27, U2.34 (E), U6.15 (A0/O3); also elsewhere on the board
MRDY: JP1.29, RN2.6 (R5), U2.36 (MRDY)
unnamed: D2.2 (A), R2.1
unnamed: J2.1, RN2.2 (R1), U3.27 (A14)
unnamed: J3.2, R12.2
unnamed: J4.3, RV1.2
unnamed: J4.15, R3.2
Q: JP1.31, U2.35 (Q)
R~W: J4.5, JP1.9, U2.32 (R/~W), U5.29 (~WE), U6.14 (LR/O4); also elsewhere on the board
R~WE: U6.19 (O4/NC); also elsewhere on the board
VCC: C1.1, C2.1, C3.1, C4.1, C5.1, C6.1, C7.1, C8.1, C9.1, C10.1, C11.1, D1.1 (K), J1.1, J4.2, JP1.1, JP2.1, JP2.2, JP2.3, JP2.4, R1.1, R2.2, R3.1, R12.1, RN1.1 (common), RN2.1 (common), RV1.1, U1.2 (VCC), U2.7 (VCC), U3.1 (VPP), U3.28 (VCC), U4.28 (VCC), U5.30 (CS2), U5.32 (VCC), U6.24 (VCC), X1.8 (Vcc); also elsewhere on the board
~65IO: U6.18 (NC/O0); also elsewhere on the board
~DMA: JP1.33, RN1.5 (R4), U2.33 (~DMA/BREQ)
~HALT: JP1.7, RN1.6 (R5), U2.40 (~HALT)
~IIC: U6.17 (A2/O1); also elsewhere on the board
~NMI: JP1.37, RN1.2 (R1), U2.2 (~NMI)
~RES: J25.2, JP1.39, R1.2, SW1.1, U1.1 (~RST), U2.37 (~RESET); also elsewhere on the board
~RW: U4.22 (~OE), U6.16 (A1/O2)

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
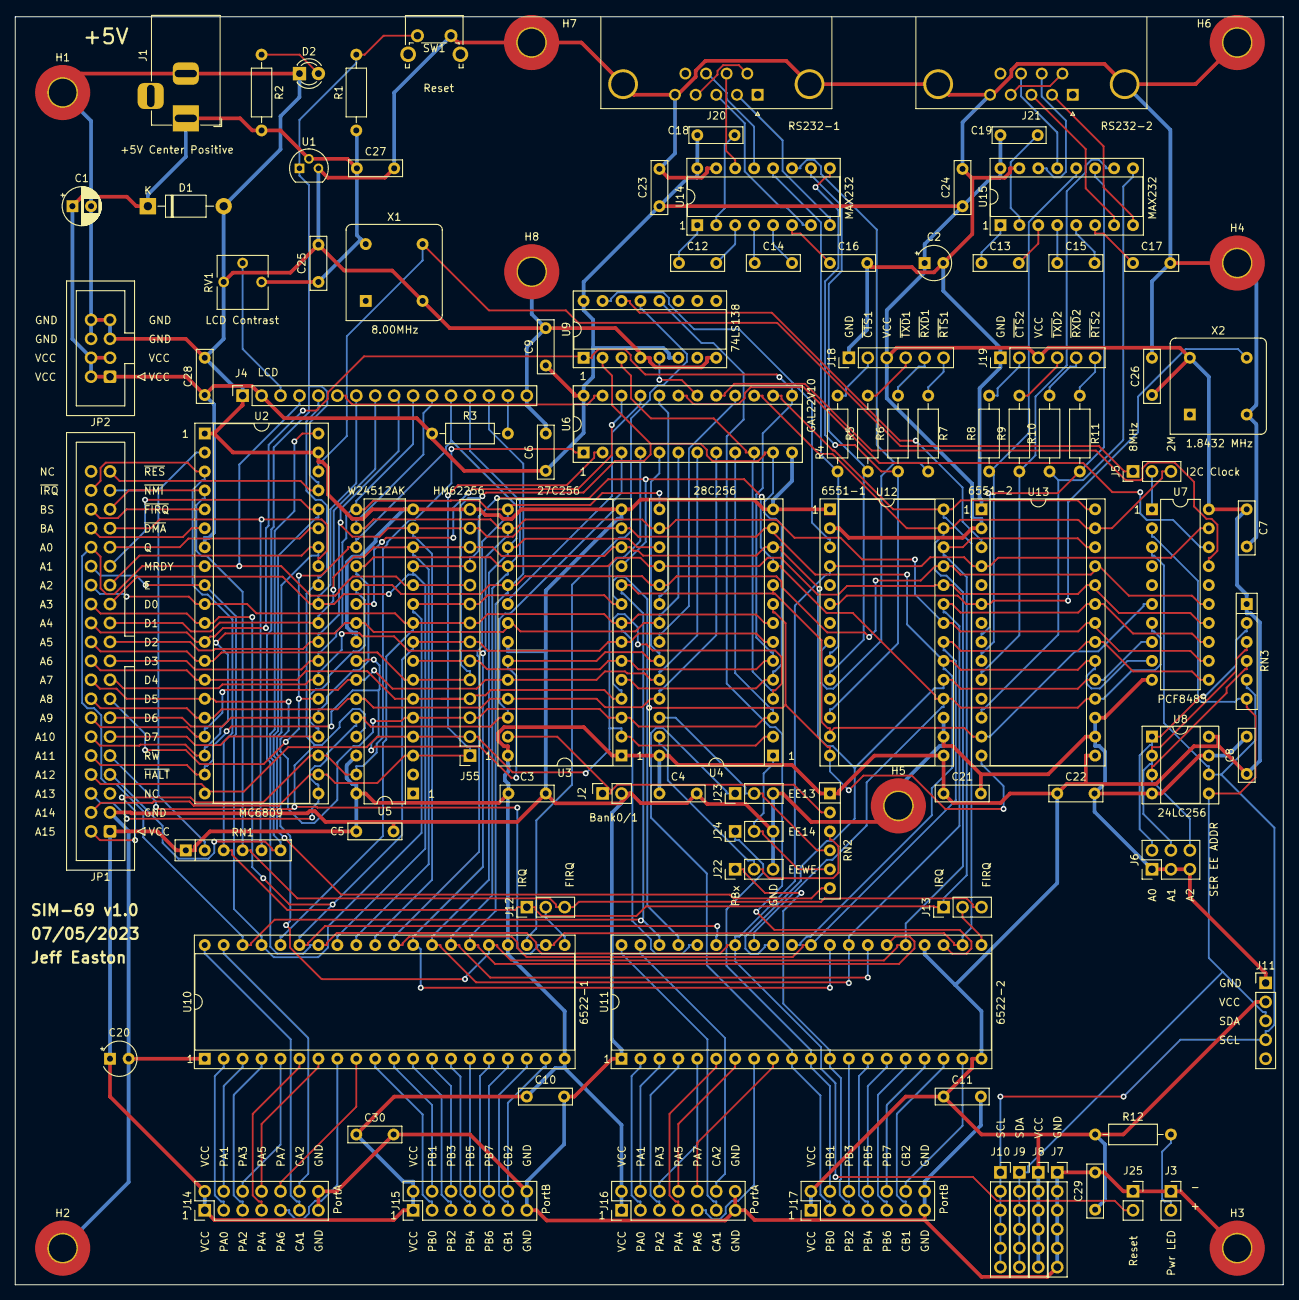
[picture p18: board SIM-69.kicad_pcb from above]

Board: 2 copper layers, 170.0 x 170.0 mm, 102 parts (0 on the bottom side), 146 nets.

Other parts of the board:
C20: 10uF; CP_Radial_Tantal_D4.5mm_P2.50mm
C21, C22, C23, C24, C25, C26, C27, C29, C30: .1uF; C_Rect_L7.0mm_W2.0mm_P5.00mm
C28: ,1uF; C_Rect_L7.0mm_W2.0mm_P5.00mm
J22: ~{EEWE}; PinHeader_1x03_P2.54mm_Vertical
J23: EE13; PinHeader_1x03_P2.54mm_Vertical
J24: EE14; PinHeader_1x03_P2.54mm_Vertical

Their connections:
PD0: J23.1; also elsewhere on the board
PD1: J24.1; also elsewhere on the board
PD2: J22.1; also elsewhere on the board
VCC: C20.1, C21.1, C22.1, C23.1, C24.1, C25.1, C26.1, C27.1, C28.1, C29.1, C30.1; also elsewhere on the board

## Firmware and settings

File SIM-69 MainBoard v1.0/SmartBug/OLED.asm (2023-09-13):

* ******************************************************
* ******************************************************
* **                                                  **
* **               OLED AND RTC I2C DEMO              **
* **                                                  **
* **                  v 1.00                          **
* **               WRITTEN 09/12/2023                 **
* **                BY JEFF EASTON                    **
* **                                                  **
* ******************************************************
* ******************************************************

* DEMO CODE.  READS THE I2C REAL TIME CLOCK EVERY SECOND.  DISPLAYS TIME ON I2C OLED DISPLAY.  
* BLINKS THE COLON BETWEEN THE HOURS AND MINUTES EVERY HALF SECOND

OLEADDR 	EQU		$78			* SSD1306 ON 2.4" 128X64 DOT MATRIX OLED DISPLAY (0111 100X).  ALTERNATE IS $7A IF DC PIN IS HIGH
P8584		EQU		$AF80		* BASE ADDRESS OF I2C CHIP
P8584SX		EQU		P8584+0		* S0/S3
P8584S1		EQU		P8584+1		* S1

* EQUATES BASED ON SMARTBUG V1.27A ASSEMBLED 09/12/2023
* IF RUNNING THIS CODE ON NEWER SB VERSIONS, THE BELOW ADDRESSES WILL NEED TO BE ADJUSTED.

I2CDADD		EQU		$033D		* I2C ADDRESS HI/LO
I2CBUFF		EQU		$033F		* I2C BUFFER
I2CWRIT		EQU		$EA64		* I2C START WRITE
I2CTXONE	EQU		$EAE5		* I2C TX ONE BYTE
I2CTX 		EQU		$EAC2		* I2C SEND COMMAND BYTES
I2CSTOP		EQU		$EA88		* I2C STOP TRANSMISSION
RTCGET		EQU		$EAF7		* GET RTC DATA INTO I2CBUFF
OLEDINIT	EQU		$ED23		* iNITIALIZE OLED PANEL
OLEDHOM		EQU		$ED4D		* OLED HOME CURSOR
OLEDCLS		EQU		$ED79		* OLED CLEAR SCREEN HOME CURSOR
WORD1		EQU		$0339		* GEN TEMP FOR WORD
WORD2		EQU		$033B		* GEN TEMP FOR WORD
DELAY		EQU		$EE65		* DELAY Y= INPUT 10uS/LOOP
CONVHL		EQU		$E076		* CONVERT LEFT HEX DIGIT TO ASCII
CONVHR		EQU		$E07A		* CONVERT RIGHT HEX DIGIT TO ASCII


			ORG		$7000
START		JSR		OLEDINIT	* INIT OLED PANEL
			JSR		OLEDCLS		* CLEAR ENTIRE PANEL
			LDX		#OLEDHEAD	* GET HEADER STRING ADDR
			JSR		OLEDSOUT	* PRINT IT ON THE OLED	(4 ROWS)
TIMELP		JSR		OLEDHOMR5	* RESET PANEL TO 5TH ROW ONLY
			LDX		#OLED5BC	* GET 5 BLANK CHARACTERS
			JSR		OLEDSOUT	* PRINT IT ON THE OLED
			JSR		RTCGET		* GET TIME FROM I2C RTC
			LDA		I2CBUFF+2	* GET HOURS
			ANDA	#%00111111	* MASK TO 2 DIGIT HOURS (24hr mode)
			JSR		CONVHL		* CONVERT HI NIBBLE TO ASCII
			STA		WORD1		* SAVE ASCII 10'S HOUR	
			LDA		I2CBUFF+2	* GET HOURS
			ANDA	#%00111111	* MASK TO 2 DIGIT HOURS
			JSR		CONVHR		* CONVERT LO NIBBLE TO ASCII
			STA		WORD1+1		* SAVE ASCII 1'S HOUR
			LDA		I2CBUFF+1	* GET MINUTES
			ANDA	#%01111111	* MASK TO 7 BITS
			JSR		CONVHL		* CONVERT HI NIBBLE TO ASCII			
			STA		WORD2		* SAVE ASCII 10'S MINUTES
			LDA		I2CBUFF+1	* GET MINUTES
			ANDA	#%01111111	* MASK TO 7 BITS
			JSR		CONVHR		* CONVERT LO NIBBLE TO ASCII		
			STA		WORD2+1		* SAVE ASCII 1'S MINUTES
			LDA		WORD1		* GET 10'S HOUR
			JSR		OLEDSENDCHR	* SEND TO OLED
			LDA		WORD1+1		* GET 1'S HOUR
			JSR		OLEDSENDCHR	* SEND TO OLED
			LDA		#$3A		* PRINT COLON
			JSR		OLEDSENDCHR	* SEND TO OLED
			LDA		WORD2		* GET 10'S MINUTES
			JSR		OLEDSENDCHR	* SEND TO OLED
			LDA		WORD2+1		* GET 1'S MINUTES
			JSR		OLEDSENDCHR	* SEND TO OLED	
			LDX		#$C350		* DELAY 1/2 SEC
			JSR     DELAY
			JSR		OLEDHOMR5	* RESET PANEL TO 5TH ROW ONLY
			LDX		#OLED5BC	* GET 5 BLANK CHARACTERS
			JSR		OLEDSOUT	* PRINT IT ON THE OLED		
			LDA		WORD1		* GET 10'S HOUR
			JSR		OLEDSENDCHR	* SEND TO OLED
			LDA		WORD1+1		* GET 1'S HOUR
			JSR		OLEDSENDCHR	* SEND TO OLED
			LDA		#$20		* PRINT SPACE
			JSR		OLEDSENDCHR	* SEND TO OLED
			LDA		WORD2		* GET 10'S MINUTES
			JSR		OLEDSENDCHR	* SEND TO OLED
			LDA		WORD2+1		* GET 1'S MINUTES
			JSR		OLEDSENDCHR	* SEND TO OLED	
			LDX		#$C350		* DELAY 1/2 SEC
			JSR     DELAY
			LBRA	TIMELP		* RESET 5TH LINE, REPEAT TIME
			
			

*
* OLED 128X64 DISPLAY, SET DISPLAY RAM START LINE TO 5 ONLY ONE ROW
*
OLEDHOMR5	LDA     #OLEADDR	* START WRITE WITH OLED ADDRESS
			JSR     I2CWRIT 
			LDA		#$00		* SET CONTROL BYTE (Co=0, D/C=0)
			JSR 	I2CTXONE
			LDA		#$21		* SET COLUMN ADDRESS (TRIPLE BYTE CONFIG)
			JSR 	I2CTXONE
			LDA		#$00		* COLUMN ADDRESS START AT 0
			JSR 	I2CTXONE
			LDA		#$7F		* COLUMN ADDRESS END AT 127
			JSR 	I2CTXONE
			LDA		#$22		* SET PAGE ADDRESS (TRIPLE BYTE CONFIG)
			JSR 	I2CTXONE
			LDA		#$04		* PAGE ADDRESS START AT 5th ROW
			JSR 	I2CTXONE
			LDA		#$04		* PAGE ADDRESS END AT 5th ROW
			JSR 	I2CTXONE
			JSR     I2CSTOP     * STOP TRANSMISSION 
			RTS		


		
*
* TEST WRITE OLED
*
POLEDTEST	LDX		#OLEDTST		* GET STRING ADDR
			JSR		OLEDSOUT		* PRINT IT ON THE OLED
			RTS
POLEDHEAD	LDX		#OLEDHEAD		* GET STRING ADDR
			JSR		OLEDSOUT		* PRINT IT ON THE OLED
			RTS
OLEDTST		FCC		'Hello World OLED'
			FCB		$04
OLEDHEAD	FCC 	'     SIM-69     '
			FCC		' By Jeff Easton '
			FCC		'                '
			FCC		' Current Time:  '
			FCB		$04
OLED5BC		FCC		'     '
			FCB 	$04
OLED6BC		FCC		'      '
			FCB 	$04
*
* PRINT ASCII STRING TO THE OLED
*
* X= ADDRESS OF ASCII STRING.  MUST END WITH $04 AND BE LESS THAN 16 CHARACTERS LONG
*  USES A
*
OLEDSOUT	LDA		,X+				* PICK UP A CHARACTER AND INC X 
			CMPA	#$04			* IS IT THE EOF MARKER?
			BEQ		OLEDSOUE		* YES SO EXIT
			JSR		OLEDSENDCHR		* SEND CHAR TO OLED
			BRA		OLEDSOUT		* LOOP FOR MORE
OLEDSOUE	RTS						* STOP TRANSMISSION	


*
* SEND ONE ASCII CHAR TO OLED
*  A = ASCII CHAR
*  USES B, PRESERVES X
*
OLEDSENDCHR	PSHS	X
			PSHS	A	
			LDA     #OLEADDR	* START WRITE WITH OLED ADDRESS
			JSR     I2CWRIT 
			LDA		#$40		* SET CONTROL BYTE (Co=0, D/C=1)
			JSR 	I2CTXONE
			LDA		#$00		* PAD FIRST COLUMN AS BLANK (5X7 CHAR IN 8X8 BLOCK)
			JSR 	I2CTXONE
			PULS	B
			SUBB	#$20		* SUBTRACT $20 FOR FIRST 20 BUTES MISSING IN TABLES
			CLRA
			TFR		D,X			* GET ASCII IN X, msb $00
			LDA		FONTC1,X	* GET FIRST COLUMN FONT PIXELS
			JSR		I2CTXONE
			LDA		FONTC2,X	* GET SECOND COLUMN FONT PIXELS
			JSR		I2CTXONE
			LDA		FONTC3,X	* GET THIRD COLUMN FONT PIXELS
			JSR		I2CTXONE
			LDA		FONTC4,X	* GET FOURTH COLUMN FONT PIXELS
			JSR		I2CTXONE
			LDA		FONTC5,X	* GET FIFTH COLUMN FONT PIXELS
			JSR		I2CTXONE
			LDA		#$00		* PAD SEVENTH COLUMN AS BLANK (5X7 CHAR IN 8X8 BLOCK)
			JSR 	I2CTXONE
			LDA		#$00		* PAD EIGHTH COLUMN AS BLANK (5X7 CHAR IN 8X8 BLOCK)
			JSR 	I2CTXONE
			JSR     I2CSTOP     * STOP TRANSMISSION 
			PULS	X
			RTS
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

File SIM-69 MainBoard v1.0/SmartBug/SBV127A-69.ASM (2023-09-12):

* ******************************************************
* ******************************************************
* **                                                  **
* **               SMARTBUG FOR THE                   **
* **                     6809                         **
* **                  v 1.27a-S69                     **
* **               WRITTEN 09/11/2023                 **
* **                BY JEFF EASTON                    **
* **                                                  **
* ******************************************************
* ******************************************************
*  
* >>> CONVERTED FROM THE MUX2 PRINTER MULTIPLEXER VERSION   <<<
* >>> SBV126C.  IE. THE Z-1000 TERMINAL CONCENTRATOR	    <<<
*
* v0.01	02/27/2022	Jeff Easton 	Change autoincrement cmds from 0,x+ to ,x+ for LWTools assembler
* V0.02	02/28/2022	Jeff Easton		Add console routines for 6850 (comment out ones not used!) moved RAMV to $0300, AUXROM $8000
* V0.03	04/17/2022	Jeff Easton		Add defs for VIA1 and P8584.  Added general drivers for i2c read/write and init, Change 6551 to 19.2Baud, 8584 i2c to 8MHz clk
* V0.04 04/22/2022	Jeff Easton		rework RTC and sEEPROM Read routines.  Add sEEPROM Write routine. 
* V0.05	04/26/2022	Jeff Easton		Add drivers for I2C LCD Module
* v0.06 07/16/2023	Jeff Easton		Ported from SB 1.26c-S50.  Added Direct Bus LCD AND Copy to Parallel EEPROM routines
* v0.07	07/17/2023	Jeff EASTON		Changed name of DL command to DS.  Added DI command for Download Intel Hex Files
* V0.08	07/21/2023	Jeff EASTON		Add CL command, RTC display and set routine
* V0.09 08/01/2023	Jeff Easton		Remap all IO from $8000 to $AF00.  Requires GAL change for 64kb RAM chip. Opens space for more ram at $8000, $9000 and most of $A000 
* V0.10	09/08/2023	JEFF EASTON		CHANGED LDS #RAMTOP TO LDS #STACK ON WARMST AND CTRLC ROUTINES, ADD EW AND CP COMMANDS, ADD I2CTXONE ROUTINE, REWRITE ALL OLED ROUTINES
* V0.11	09/12/2023	JEFF EASTON		ADDED BANK SWITCHING FOR EEPROM, ADDED ER, EEPROM READ COMMAND.  VERSION 1.27a RELEASE
*
* THESE ARE THE CONSTANTS THAT THE ROM IS 
* ASSEMBLED WITH.
*
RAM     EQU		$0000		* BASE OF RAM PAGE
RAMTOP  EQU		$00FF		* TOP OF DIRECT PAGE
STACK	EQU		$01FF		* TOP OF SYSTEM STACK
USTACK	EQU		$02FF		* TOP OF USER STACK
RAMV	EQU		$0300		* START OF VAR. STORAGE
ACIA	EQU		$AF00		* DEFAULT SERIAL PORT 6551-1 (base of all IO)
ACIA2	EQU		$AF10		* SECONDARY SERIAL PORT 6551-2
ACIA8	EQU		$AFF0		* ALTERNATE SERIAL PORT 6850 (NOT USED)
VIA1	EQU		$AF20		* VIA #1 BASE ADDRESS 6522-1
VIA2	EQU		$AF30		* VIA #2 BASE ADDRESS 6522-2
P8584	EQU		$AF80		* BASE ADDRESS OF I2C CHIP
LCDB	EQU		$AF90		* BASE OF DIRECT BUS LCD MODULE
EEPROM	EQU		$B000		* BASE OF WRITEABLE EEPROM (28c64) 8k SPACE (BANKABLE WITH 28c256)
AUXROM	EQU		EEPROM		* AUXILIARY ROM START ADDRESS
*
* I2C DEVICES
*
RTCADDR	EQU		$D0			* DS1307 REAL TIME CLOCK ADDRESS (1101 000X)
SEEADDR	EQU		$AE			* 24LC256 SERIAL 32KB EEPROM (1010 111X) IE A2, A1 A0 =HI, (ALL JUMPERS OUT)
SECADDR	EQU		$A0			* 24c32 SERIAL 8KB EEPROM (1010 000X) IE A2, A2, A0 =LO, (ALL PINS GND) OPTIONAL SERIAL EEPROM ON SOME RTC BOARDS
LCDADDR	EQU		$4E			* PCF8574T I2C TO PARALLEL CHIP (0100111X)ON I2C LCD PANEL (HLF PCF8574T, T.I. CLONE) 
OLEADDR	EQU		$78			* SSD1309 ON 2.4" 128X64 DOT MATRIX OLED DISPLAY (0111 100X).  ALTERNATE IS $7A IF DC PIN IS HIGH
*
*
*
* SYSTEM CONSOLE I/O DEFAULT  >>> SY6551 ACIA <<<
*
ACIADR  EQU		ACIA		* ACIA DATA REGISTER
ACIASR  EQU		ACIA+1		* ACIA STATUS REGISTER
ACIACR	EQU		ACIA+2		* ACIA COMMAND REGISTER
ACIATR	EQU		ACIA+3		* ACIA CONTROL REGISTER
*
* SYSTEM CONSOLE I/O ALTERNATE  >>> MC6850 ACIA <<<
*
ACIA8CR	EQU		ACIA8		* 6850 CONTROL AND STATUS REGISTER
ACIA8DR	EQU		ACIA8+1		* 6850 DATA REGISTER
*
* VIA #1	>>> SY6522-1 <<<
*
VIA1ORB	EQU		VIA1		* ORB/IRB PORT B OUTPUT/INPUT
VIA1ORA	EQU		VIA1+1		* ORA/IRA PORT A OUTPUT/INPUT
VIA1DRB	EQU		VIA1+2		* DDRB DATA DIRECTION REGISTER B
VIA1DRA	EQU		VIA1+3		* DDRA DATA DIRECTION REGISTER A
*
* VIA #2	>>> SY6522-2 <<<
*
VIA2ORB	EQU		VIA2		* ORB/IRB PORT B OUTPUT/INPUT
VIA2ORA	EQU		VIA2+1		* ORA/IRA PORT A OUTPUT/INPUT
VIA2DRB	EQU		VIA2+2		* DDRB DATA DIRECTION REGISTER B
VIA2DRA	EQU		VIA2+3		* DDRA DATA DIRECTION REGISTER A
*
* P8584 I2C REGISTERS
*
P8584SX	EQU		P8584+0		* S0/S3
P8584S1	EQU		P8584+1		* S1
*
* LCD MODULE DIRECT BUS REGISTERS
*
LCDBIR	EQU		LCDB+0		* LCD DIRECT BUS INSTRUCTION REGISTER
LCDBDR	EQU		LCDB+1		* LCD DIRECT BUS DATA REGISTER
*
* AUXILIARY ROM TABLE STRUCTURE DEFINITIONS
*
AUXCLD	EQU		AUXROM		* AUX ROM COLD START VECTOR
AUXWRM	EQU		AUXROM+2	* AUX ROM WARM START VECTOR
AUXERR	EQU		AUXROM+4	* AUX ROM ERROR HANDLER VECTOR
AUXFLG	EQU		AUXROM+6	* AUX ROM FLAG FOR AUTO START eg '6809'
AUXTFL	EQU		AUXROM+10	* AUX ROM FLAG FOR JUMP TABLE EXTENSION eg 'ETAB'	
AUXTBL	EQU		AUXROM+14	* AUX ROM JUMP TABLE VECTOR
AUXVER	EQU		AUXROM+16	* AUX ROM VERSION NUMBER eg '1.00'
*
*
*
* SET VECTORS AND TABLE SPACE
*
	ORG	RAMV				* SET TO VECTOR SPACE
*
SW3VEC  RMB     2			* SWI3 INTERRUPT VECTOR
SW2VEC  RMB     2			* SWI2 INT. VECTOR
FIRVEC  RMB     2			* FIRQ INT. VECTOR
IRQVEC  RMB     2			* IRQ INT. VECTOR
SWIVEC  RMB     2			* SWI INT. VECTOR
NMIVEC  RMB     2			* NMI INT. VECTOR
USEVEC  RMB     2			* USER COMMAND VEC.
INVEC   RMB     2			* CONSOLE INPUT VEC.
OUTVEC  RMB     2			* CONSOLE OUTPUT VEC.
PRIVEC	RMB		2			* PRINTER DRIVER VEC.
EXTVEC	RMB		2			* AUX ROM JUMP TABLE EXTENSION
*
SAVECC  RMB     1			* TEMP REGISTER STORAGE
SAVEA   RMB     1			* FOR SWI INT. ROUTINE
SAVEB   RMB     1 
SAVEDP  RMB     1 
SAVEX   RMB     2 
SAVEY	RMB		2
SAVEU	RMB		2	
SAVEPC	RMB		2	
SAVES 	RMB		2	
SAVED 	RMB		2	
*
BEGADD  RMB     2			* RANGE ADDRESS
ENDADD  RMB     2
*
FINCNT	RMB		1			* NUMBER OF BYTES TO FIND
FINBY1	RMB		1			* STORAGE OF BYTE 1
FINBY2	RMB		1			* STORAGE OF BYTE 2
FINBY3	RMB		1			* STORAGE OF BYTE 3
FINBY4	RMB		1			* STORAGE OF BYTE 4
PRNORM	RMB		2			* 
PRFLAG	RMB		1			* PRINTER OUTPUT FLAG
LCMAP	RMB		1			* LC -> UC MAPPING BYTE
EXTFLG	RMB		1			* AUX ROM EXT. JUMP TABLE FLAG
XOFLAG	RMB		1			* XON/XOFF FLAG
XONORM	RMB		2
BYTE1	RMB		1			* GENERAL TEMP AREA
BYTE2	RMB		1			* GENERAL TEMP AREA
WORD1	RMB		2			* GEN TEMP FOR WORD
WORD2	RMB		2			* GEN TEMP FOR WORD
I2CDADD	RMB		2			* ADDRESS HI/LO BYTES FOR ADDRESSABLE I2C DEVICE SUCH AS SERIAL EEPROM
I2CBUFF	RMB		32			* BUFFER FOR I2C DATA
*
*
*
*
*
		ORG		$E000		* START OF SB ROM CODE
*
*
* ENTRY POINTS INTO MONITOR
*
COLDST	JMP		BOOT		* COLD ENTRY POINT TO MONITOR
WARMST	JMP		WARM		* WARM ENTRY POINT TO MONITOR
LOG		JMP		LOGON		* ENTRY FROM AUX ROM-SKIP INIT
*
*
* SUBROUTINES USED BY ALL ROUTINES 
* IN SMARTBUG
*
*
* INPUT A WORD FROM CONSOLE
*
*	USES BYTE ROUTINE TWICE TO GET A 16 BIT WORD
*	FROM KEYBOARD.  WORD IS IN X ON EXIT
*
WORD	BSR		BYTE		* READ 2 FRAMES
		STA		WORD1		* PUT HI BYTE IN
		BSR		BYTE		* GET NEXT BYTE
		STA		WORD1+1		* PUT LO BYTE IN
		LDX		WORD1		* GET WORD IN X
		RTS
*
* INPUT A BYTE FROM CONSOLE
*
*	GETS TWO KEYPRESSES, CONVERTS TO A TWO DIGIT
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
